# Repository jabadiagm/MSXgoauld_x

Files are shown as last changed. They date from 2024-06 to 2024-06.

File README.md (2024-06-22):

# MSXgoauld_x
MSX Goa'uld board with Xilinx XC7A35T

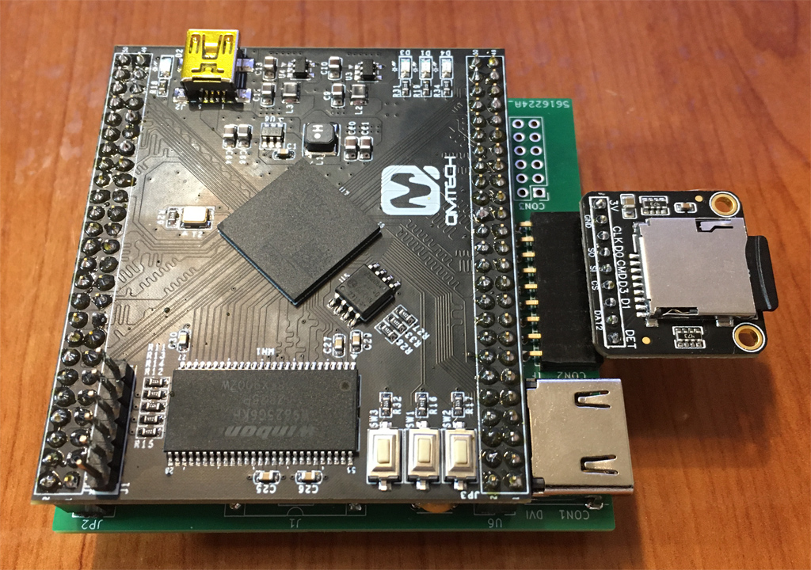
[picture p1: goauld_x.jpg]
goauld_x


MSX2+ engine in Z80 socket. It turns one MSX into an MSX2+ by replacing Z80 processor. FPGA in board contains: 
* Z80
* V9958 with hdmi output
* MSX2+ BIOS
* 4MB mapper
* RTC
* PSG through hdmi
* SCC (audio only) through hdmi
* OPLL through hdmi
* SD card interface with Nextor

## How it works:
Logic acts on bus control signals so that internal devices inside fpga take priority over external devices. 

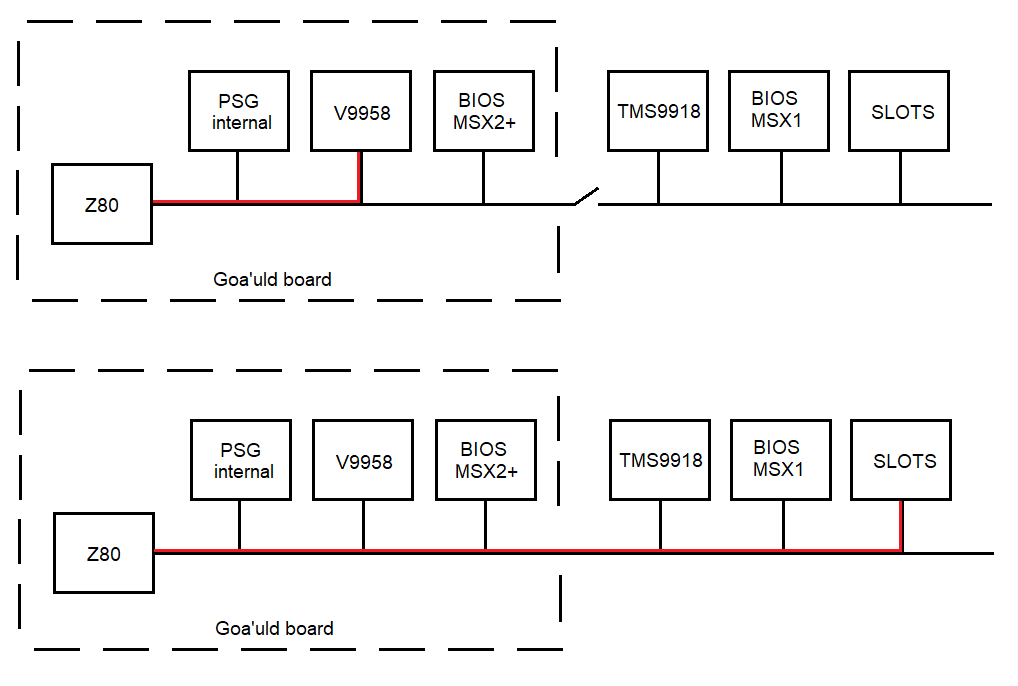
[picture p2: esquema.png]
Esquema


## Slot map

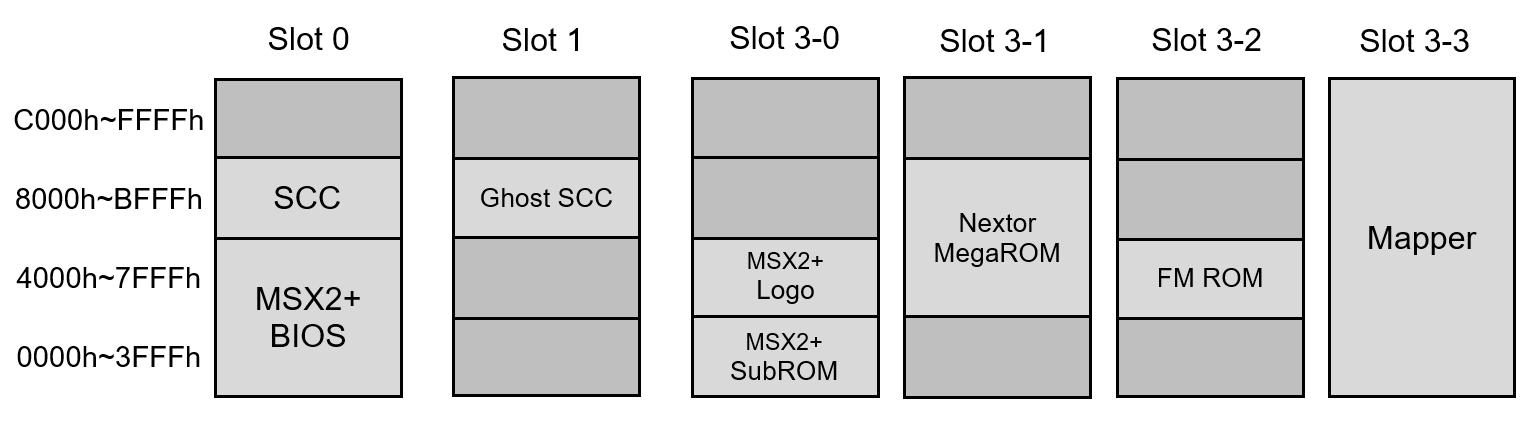
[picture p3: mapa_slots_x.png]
Slot map


Place SCC cartridges in slot 1 to get SCC sound through HDMI

## Revision 1 Board
PCB version 1 uses through hole components for ease of assembly

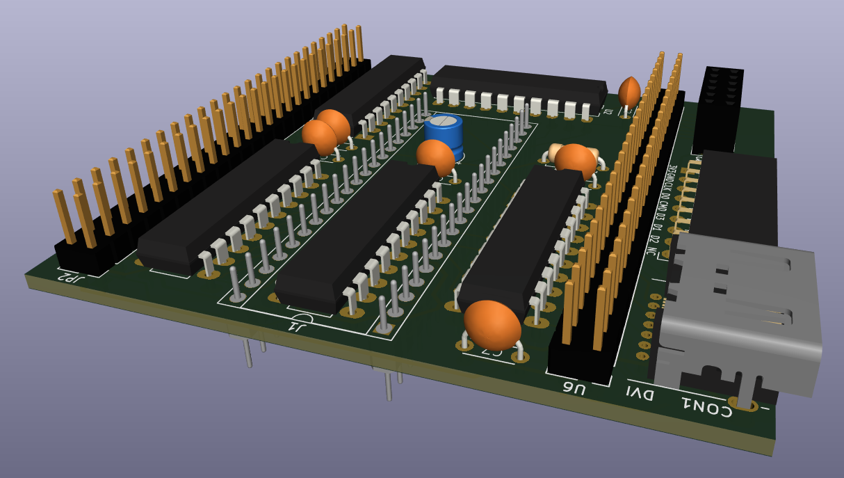
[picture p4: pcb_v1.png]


## Revision 2 Board

Revision 2 uses SOIC-20, TSSOP-20 for 74LS245 and 74LVC245 ICs, which are smaller:

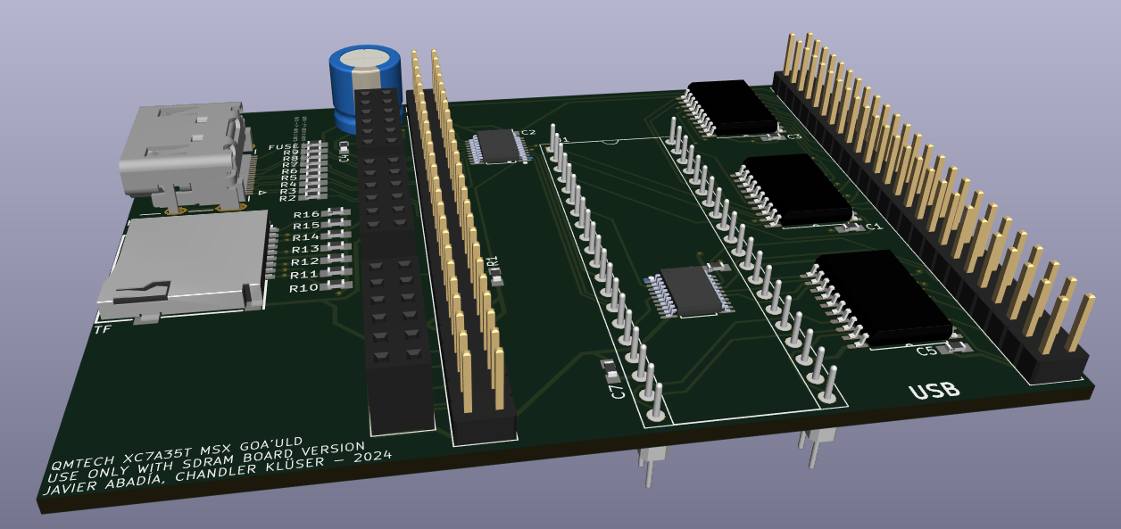
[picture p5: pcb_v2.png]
Revision 2


## Bill of materials
Main elements:
* [QMTECH Xilinx FPGA Artix7 Artix-7 XC7A35T SDRAM Core Board](https://a.aliexpress.com/_EIR63QR)
* [(PCB V1) SD SPI or SDIO Card Breakout Board - 3V](https://a.aliexpress.com/_EJ8GIw7)
* [(PCB V1) HDMI female socket/plug 19P female mount 3-row pins](https://a.aliexpress.com/_Eub6hh9)
* [40Pin Connector Header Round Needle Gold Plated 1x40 Golden Pin Single Row Male 2.54mm Breakable Pin Connector Strip](https://a.aliexpress.com/_ExPDv4F)
* [dip 2*40/ PIN double row PIN HEADER 2.54MM PITCH MALE Strip Connector 2X](https://a.aliexpress.com/_EJbEXl9)
* [2.54mm Double Row Straight Female Pin Header Socket Connector 2x25Pin](https://a.aliexpress.com/_EvLvXL1)
* 2xSN74LVC245AN
* 3x74LS245
* Platform Cable USB II / DLC10 (programmer)

## Tips/Warnings
* HDMI circuitry is unprotected in V1 board, use at your own risk
* Turn on monitor after turning on MSX, otherwise fpga may not start
* When possible, use a linear power supply to keep electrical noises low
* Get integrated circuits from trusted sources
* Use turned pins in header to avoid damages in Z80 socket
* Board is sensitive to dirty electrical contacts, way more than Z80. Keep cartridge & Z80 socket contacts clean

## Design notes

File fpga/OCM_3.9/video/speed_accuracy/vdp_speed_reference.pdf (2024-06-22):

“MOST COMMON REFERENCE FOR THE VDP SPEED ACCURACY”

PANASONIC FS-A1GT MSX turbo R / R800 (Z80 MODE) / VDP V9958

The tables for the copies:

LMMM accuracy: 16 | HMMM accuracy: 32 | YMMM accuracy: 32
TESTCOPY FS-A1GT X=32 | TESTCOPY FS-A1GT X=64 | TESTCOPY FS-A1GT X=64
Spr / Lin - Speed 50/60Hz | Spr / Lin - Speed 50/60Hz | Spr / Lin - Speed 50/60Hz
on / 212 - 1232 / 976 | on / 212 - 3520 / 2784 | on / 212 - 4192 / 3168
on / 192 - 1264 / 1008 | on / 192 - 3616 / 2880 | on / 192 - 4384 / 3360
off / 212 - 1584 / 1312 | off / 212 - 4352 / 3616 | off / 212 - 5856 / 4832
off / 192 - 1584 / 1312 | off / 192 - 4384 / 3648 | off / 192 - 5856 / 4864
--Blank-- - 1600 / 1328 | --Blank-- - 4512 / 3744 | --Blank-- - 6112 / 5120

The tables for the fills:

LMMV accuracy: 16 | HMMV accuracy: 64
TESTCOPY FS-A1GT X=32 | TESTCOPY FS-A1GT X=128
Spr / Lin - Speed 50/60Hz | Spr / Lin - Speed 50/60Hz
on / 212 - 1696 / 1344 | on / 212 - 7040 / 5632
on / 192 - 1728 / 1392 | on / 192 - 7168 / 5760
off / 212 - 1840 / 1488 | off / 212 - 7232 / 5888
off / 192 - 1856 / 1504 | off / 192 - 7360 / 5952
--Blank-- - 2128 / 1776 | --Blank-- - 8448 / 7040

The table for the lines:

LINE accuracy: 32
TESTCOPY FS-A1GT X=8 Y=8

Spr / Lin - Speed 50/60Hz

on / 212 - | 3936 | / | 3264
on / 192 - | 3968 | / | 3296
off / 212 - | 4096 | / | 3392
off / 192 - | 4096 | / | 3392
--Blank-- - | 4224 | / | 3520
( on / 212 )

Notes:

- Speed is indicated in bytes per interrupt.
- On “TestCopy” program LINES = SPEED / ACCURACY.
- The CPU frequency for the test is 3.58MHz.

The above values have been verified by KdL, 2018.05.14 These information refers to: http://map.grauw.nl/articles/vdp_commands_speed.php

More information to get the most accurate LINE speed (not yet implemented in OCM): http://map.grauw.nl/articles/vdp-vram-timing/vdp-timing.htmlhttp://map.grauw.nl/articles/vdp-vram-timing/vdp-timing-2.html

“MOST COMMON REFERENCE FOR THE VDP SPEED ACCURACY”

PHILIPS NMS-8245 MSX2 / Z80 / VDP V9938

The tables for the copies:

LMMM accuracy: 16 | HMMM accuracy: 32 | YMMM accuracy: 32
TESTCOPY NMS-8245 X=32 | TESTCOPY NMS-8245 X=64 | TESTCOPY NMS-8245 X=64
Spr / Lin - Speed 50/60Hz | Spr / Lin - Speed 50/60Hz | Spr / Lin - Speed 50/60Hz
on / 212 - 1232 / 976 | on / 212 - 3520 / 2784 | on / 212 - 4192 / 3168
on / 192 - 1264 / 1008 | on / 192 - 3616 / 2880 | on / 192 - 4384 / 3360
off / 212 - 1584 / 1312 | off / 212 - 4352 / 3616 | off / 212 - 5856 / 4832
off / 192 - 1584 / 1312 | off / 192 - 4384 / 3648 | off / 192 - 5856 / 4864
--Blank-- - 1600 / 1328 | --Blank-- - 4512 / 3744 | --Blank-- - 6112 / 5120

The tables for the fills:

LMMV accuracy: 16 | HMMV accuracy: 64
TESTCOPY NMS-8245 X=32 | TESTCOPY NMS-8245 X=128
Spr / Lin - Speed 50/60Hz | Spr / Lin - Speed 50/60Hz
on / 212 - 1696 / 1344 | on / 212 - 7040 / 5632
on / 192 - 1728 / 1392 | on / 192 - 7168 / 5760
off / 212 - 1840 / 1488 | off / 212 - 7232 / 5888
off / 192 - 1856 / 1504 | off / 192 - 7360 / 5952
--Blank-- - 2128 / 1776 | --Blank-- - 8448 / 7040

The table for the lines:

LINE accuracy: 32
TESTCOPY NMS-8245 X=8 Y=8

Spr / Lin - Speed 50/60Hz

on / 212 - | 4096 | / | 3392
on / 192 - | 4128 | / | 3424
off / 212 - | 4224 | / | 3520
off / 192 - | 4256 | / | 3520
--Blank-- - | 4352 | / | 3648
( on / 212 )

Notes:

- Speed is indicated in bytes per interrupt.
- On “TestCopy” program LINES = SPEED / ACCURACY.
- The CPU frequency for the test is 3.58MHz.

The above values have been verified by KdL, 2018.05.14 These information refers to: http://map.grauw.nl/articles/vdp_commands_speed.php

More information to get the most accurate LINE speed (not yet implemented in OCM): http://map.grauw.nl/articles/vdp-vram-timing/vdp-timing.htmlhttp://map.grauw.nl/articles/vdp-vram-timing/vdp-timing-2.html

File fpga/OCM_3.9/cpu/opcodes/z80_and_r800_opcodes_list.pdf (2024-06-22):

## Z80 And R800 Opcodes List

### Opcodes on single-byte

| 00 | 01 | 02 | 03 | 04 | 05 | 06 | 07 | 08 | 09 | 0A | 0B | 0C | 0D | 0E | 0F
00 | NOP | LD BC,ad | LD (BC),A | INC BC | INC B | DEC B | LD B,v | RLCA | EX AF,AF' | ADD HL,BC | LD A,(BC) | DEC BC | INC C | DEC C | LD C,v | RRCA
10 | DJNZ v | LD DE,ad | LD (DE),A | INC DE | INC D | DEC D | LD D,v | RLA | JR v | ADD HL,DE | LD A,(DE) | DEC DE | INC E | DEC E | LD E,v | RRA
20 | JR nz,v | LD HL,ad | LD (ad),HL | INC HL | INC H | DEC H | LD H,v | DAA | JR z,v | ADD HL,HL | LD HL,(ad) | DEC HL | INC L | DEC L | LD L,v | CPL
30 | JR nc,v | LD SP,ad | LD (ad),A | INC SP | INC (HL) | DEC (HL) | LD (HL),v | SCF | JR C,v | ADD HL,SP | LD A,(ad) | DEC SP | INC A | DEC A | LD A,v | CCF
40 | LD B,B | LD B,C | LD B,D | LD B,E | LD B,H | LD B,L | LD B,(HL) | LD B,A | LD C,B | LD C,C | LD C,D | LD C,E | LD C,H | LD C,L | LD C,(HL) | LD C,A
50 | LD D,B | LD D,C | LD D,D | LD D,E | LD D,H | LD D,L | LD D,(HL) | LD D,A | LD E,B | LD E,C | LD E,D | LD E,E | LD E,H | LD E,L | LD E,(HL) | LD E,A
60 | LD H,B | LD H,C | LD H,D | LD H,E | LD H,H | LD H,L | LD H,(HL) | LD H,A | LD L,B | LD L,C | LD L,D | LD L,E | LD L,H | LD L,L | LD L,(HL) | LD L,A
70 | LD (HL),B | LD (HL),C | LD (HL),D | LD (HL),E | LD (HL),H | LD (HL),L | HALT | LD (HL),A | LD A,B | LD A,C | LD A,D | LD A,E | LD A,H | LD A,L | LD A,(HL) | LD A,A
80 | ADD A,B | ADD A,C | ADD A,D | ADD A,E | ADD A,H | ADD A,L | ADD A,(HL) | ADD A,A | ADC A,B | ADC A,C | ADC A,D | ADC A,E | ADC A,H | ADC A,L | ADC A,(HL) | ADC A,A
90 | SUB B | SUB C | SUB D | SUB E | SUB H | SUB L | SUB (HL) | SUB A | SBC A,B | SBC A,C | SBC A,D | SBC A,E | SBC A,H | SBC A,L | SBC A,(HL) | SBC A
A0 | AND B | AND C | AND D | AND E | AND H | AND L | AND (HL) | AND A | XOR B | XOR C | XOR D | XOR E | XOR H | XOR L | XOR (HL) | XOR A
B0 | OR B | OR C | OR D | OR E | OR H | OR L | OR (HL) | OR A | CP B | CP C | CP D | CP E | CP H | CP L | CP (HL) | CP A
C0 | RET nz | POP BC | JP nz,ad | JP ad | CALL nz,ad | PUSH BC | ADD A,v | RST 0h | RET z | RET | JP z,ad | * | CALL z,ad | CALL ad | ADC A,v | RST 8h
D0 | RET nc | POP DE | JP nc,ad | OUT (v),A | CALL nc,ad | PUSH DE | SUB v | RST 10h | RET c | EXX | JP c,ad | IN A,(v) | CALL c,ad | ** | SBC A,v | RST 18h
E0 | RET po | POP HL | JP po,ad | EX (SP),HL | CALL po,ad | PUSH HL | AND v | RST 20h | RET pe | JP (HL) | JP pe,ad | EX DE,HL | CALL pe,ad | *** | XOR v | RST 28h
F0 | RET p | POP AF | JP p,ad | DI | CALL p,ad | PUSH AF | OR v | RST 30h | RET m | LD SP,HL | JP m,ad | EI | CALL m,ad | **** | CP v | RST 38h

Note: Some of these opcodes are followed by one or two bytes to specify the value v or the address ad.

### (*) Opcodes extended on 2-byte which begin with CBh

CB | 00 | 01 | 02 | 03 | 04 | 05 | 06 | 07 | 08 | 09 | 0A | 0B | 0C | 0D | 0E | 0F
00 | RLC B | RLC C | RLC D | RLC E | RLC H | RLC L | RLC (HL) | RLC A | RRC B | RRC C | RRC D | RRC E | RRC H | RRC H | RRC (HL) | RRC A
10 | RL B | RL C | RL D | RL E | RL H | RL L | RL (HL) | RL A | RR B | RR C | RR D | RR E | RR H | RR H | RR (HL) | RR A
20 | SLA B | SLA C | SLA D | SLA E | SLA H | SLA L | SLA (HL) | SLA A | SRA B | SRA C | SRA D | SRA E | SRA H | SRA H | SRA (HL) | SRA A
30 | SLL B | SLL C | SLL D | SLL E | SLL H | SLL L | SLL (HL) | SLL A | SRL B | SRL C | SRL D | SRL E | SRL H | SRL H | SRL (HL) | SRL A
40 | BIT 0,B | BIT 0,C | BIT 0,D | BIT 0,E | BIT 0,H | BIT 0,L | BIT 0,(HL) | BIT 0,A | BIT 1,B | BIT 1,C | BIT 1,D | BIT 1,E | BIT 1,H | BIT 1,L | BIT 1,(HL) | BIT 1,A
50 | BIT 2,B | BIT 2,C | BIT 2,D | BIT 2,E | BIT 2,H | BIT 2,L | BIT 2,(HL) | BIT 2,A | BIT 3,B | BIT 3,C | BIT 3,D | BIT 3,E | BIT 3,H | BIT 3,L | BIT 3,(HL) | BIT 3,A
60 | BIT 4,B | BIT 4,C | BIT 4,D | BIT 4,E | BIT 4,H | BIT 4,L | BIT 4,(HL) | BIT 4,A | BIT 5,B | BIT 5,C | BIT 5,D | BIT 5,E | BIT 5,H | BIT 5,L | BIT 5,(HL) | BIT 5,A
70 | BIT 6,B | BIT 6,C | BIT 6,D | BIT 6,E | BIT 6,H | BIT 6,L | BIT 6,(HL) | BIT 6,A | BIT 7,B | BIT 7,C | BIT 7,D | BIT 7,E | BIT 7,H | BIT 7,L | BIT 7,(HL) | BIT 7,A
80 | RES 0,B | RES 0,C | RES 0,D | RES 0,E | RES 0,H | RES 0,L | RES 0,(HL) | RES 0,A | RES 1,B | RES 1,C | RES 1,D | RES 1,E | RES 1,H | RES 1,L | RES 1,(HL) | RES 1,A
90 | RES 2,B | RES 2,C | RES 2,D | RES 2,E | RES 2,H | RES 2,L | RES 2,(HL) | RES 2,A | RES 3,B | RES 3,C | RES 3,D | RES 3,E | RES 3,H | RES 3,L | RES 3,(HL) | RES 3,A
A0 | RES 4,B | RES 4,C | RES 4,D | RES 4,E | RES 4,H | RES 4,L | RES 4,(HL) | RES 4,A | RES 5,B | RES 5,C | RES 5,D | RES 5,E | RES 5,H | RES 5,L | RES 5,(HL) | RES 5,A
B0 | RES 6,B | RES 6,C | RES 6,D | RES 6,E | RES 6,H | RES 6,L | RES 6,(HL) | RES 6,A | RES 7,B | RES 7,C | RES 7,D | RES 7,E | RES 7,H | RES 7,L | RES 7,(HL) | RES 7,A
C0 | SET 0,B | SET 0,C | SET 0,D | SET 0,E | SET 0,H | SET 0,L | SET 0,(HL) | SET 0,A | SET 1,B | SET 1,C | SET 1,D | SET 1,E | SET 1,H | SET 1,L | SET 1,(HL) | SET 1,A
D0 | SET 2,B | SET 2,C | SET 2,D | SET 2,E | SET 2,H | SET 2,L | SET 2,(HL) | SET 2,A | SET 3,B | SET 3,C | SET 3,D | SET 3,E | SET 3,H | SET 3,L | SET 3,(HL) | SET 3,A
E0 | SET 4,B | SET 4,C | SET 4,D | SET 4,E | SET 4,H | SET 4,L | SET 4,(HL) | SET 4,A | SET 5,B | SET 5,C | SET 5,D | SET 5,E | SET 5,H | SET 5,L | SET 5,(HL) | SET 5,A
F0 | SET 6,B | SET 6,C | SET 6,D | SET 6,E | SET 6,H | SET 6,L | SET 6,(HL) | SET 6,A | SET 7,B | SET 7,C | SET 7,D | SET 7,E | SET 7,H | SET 7,L | SET 7,(HL) | SET 7,A

### (**) Opcodes extended on two-byte which begin with DDh (for register IX)

DD | 00 | 01 | 02 | 03 | 04 | 05 | 06 | 07 | 08 | 09 | 0A | 0B | 0C | 0D | 0E | 0F
00 | | | | | | | | | | ADD IX,BC
10 | | | | | | | | | | ADD IX,DE
20 | | LD IX,ad | LD (ad),IX | INC IX | INC IXH | DEC IXH | LD IXH,v | | | ADD IX,IX | LD IX,(ad) | DEC IX | INC IXL | DEC IXL | LD IXL,v
30 | | | | | INC (IX+v) | DEC (IX+v) | LD (IX+v),v | | | ADD IX,SP
40 | | | | | LD B,IXH | LD B,IXL | LD B,(IX+v) | | | | | | LD C,IXH | LD C,IXL | LD C,(IX+v)
50 | | | | | LD D,IXH | LD D,IXL | LD D,(IX+v) | | | | | | LD E,IXH | LD E,IXL | LD E,(IX+v)
60 | LD IXH,B | LD IXH,C | LD IXH,D | LD IXH,E | LD IXH,IXH | LD IXH,IXL | LD H,(IX+v) | LD IXH,A | LD IXL,B | LD IXL,C | LD IXL,D | LD IXL,E | LD IXL,IXH | LD IXL,IXL | LD L,(IX+v) | LD IXL,A
70 | LD (IX+v),B | LD (IX+v),C | LD (IX+v),D | LD (IX+v),E | LD (IX+v),H | LD (IX+v),L | | LD (IX+v),A | | | | | LD A,IXH | LD A,IXL | LD A,(IX+v)
80 | | | | | ADD A,IXH | ADD A,IXL | ADD A,(IX+v) | | | | | | ADC A,IXH | ADC A,IXL | ADC A,(IX+v)
90 | | | | | SUB IXH | SUB IXL | SUB (IX+v) | | | | | | SBC A,IXH | SBC A,IXL | SBC A,(IX+v)
A0 | | | | | AND IXH | AND IXL | AND (IX+v) | | | | | | XOR IXH | XOR IXL | XOR (IX+v)
B0 | | | | | OR IXH | OR IXL | OR (IX+v) | | | | | | CP IXH | CP IXL | CP (IX+v)
C0 | | | | | | | | | | | | **²

D0
E0 | | POP IX | | EX (SP),IX | | PUSH IX | | | | JP (IX)
F0 | | | | | | | | | | LD SP,IX

Note: Some of these opcodes are followed by one or two bytes to specify the value v or the address ad.

### (**²) Opcodes extended on four-byte which begin with DDh+CBh+v (for register IX)

DD+CB+v | 00 | 01 | 02 | 03 | 04 | 05 | 06 | 07 | 08 | 09 | 0A | 0B | 0C | 0D | 0E | 0F
00 | RLC (v+IX) LD B,(v+IX) | RLC (IX+v) LD C,(IX+v) | RLC (v+IX) LD D,(v+IX) | RLC (v+IX) LD E,(v+IX) | RLC (v+IX) LD H,(v+IX) | RLC (v+IX) LD L,(v+IX) | RLC (v+IX) | RLC (v+IX) LD A,(v+IX) | RRC (v+IX) LD B,(v+IX) | RRC (v+IX) LD C,(v+IX) | RRC (v+IX) LD D,(v+IX) | RRC (v+IX) LD E,(v+IX) | RRC (v+IX) LD H,(v+IX) | RRC (v+IX) LD L,(v+IX) | RRC (v+IX) | RRC (v+IX) LD A,(v+IX)
10 | RL (v+IX) LD B,(v+IX) | RL (IX+v) LD C,(IX+v) | RL (v+IX) LD D,(v+IX) | RL (v+IX) LD E,(v+IX) | RL (v+IX) LD H,(v+IX) | RL (v+IX) LD L,(v+IX) | RL (v+IX) | RL (v+IX) LD A,(v+IX) | RR (v+IX) LD B,(v+IX) | RR (v+IX) LD C,(v+IX) | RR (v+IX) LD D,(v+IX) | RR (v+IX) LD E,(v+IX) | RR (v+IX) LD H,(v+IX) | LD L,(v+IX) RR (v+IX) | RR (v+IX) | RR (v+IX) LD A,(v+IX)
20 | SLA (v+IX) LD B,(v+IX) | SLA (IX+v) LD C,(IX+v) | SLA (v+IX) LD D,(v+IX) | SLA (v+IX) LD E,(v+IX) | SLA (v+IX) LD H,(v+IX) | SLA (v+IX) LD L,(v+IX) | SLA (v+IX) | SLA (v+IX) LD A,(v+IX) | SRA (v+IX) LD B,(v+IX) | SRA (v+IX) LD C,(v+IX) | SRA (v+IX) LD D,(v+IX) | SRA (v+IX) LD E,(v+IX) | SRA (v+IX) LD H,(v+IX) | SRA (v+IX) LD L,(v+IX) | SRA (v+IX) | SRA (v+IX) LD A,(v+IX)
30 | SLL (v+IX) LD B,(v+IX) | SLL (IX+v) LD C,(IX+v) | SLL (v+IX) LD D,(v+IX) | SLL (v+IX) LD E,(v+IX) | SLL (v+IX) LD H,(v+IX) | SLL (v+IX) LD L,(v+IX) | SLL (v+IX) | SRL (v+IX) LD A,(v+IX) | SRL (v+IX) LD B,(v+IX) | SRL (v+IX) LD C,(v+IX) | SRL (v+IX) LD D,(v+IX) | SRL (v+IX) LD E,(v+IX) | SRL (v+IX) LD H,(v+IX) | SRL (v+IX) LD L,(v+IX) | SRL (v+IX) | SRL (v+IX) LD A,(v+IX)
40 | BIT 0,(v+IX) LD B,(v+IX) | BIT 0,(IX+v) LD C,(IX+v) | BIT 0,(v+IX) LD D,(v+IX) | BIT 0,(v+IX) LD E,(v+IX) | BIT 0,(v+IX) LD H,(v+IX) | BIT 0,(v+IX) LD L,(v+IX) | BIT 0, (v+IX) | BIT 0,(v+IX) LD A,(v+IX) | BIT 1,(v+IX) LD B,(v+IX) | BIT 1,(v+IX) LD C,(v+IX) | BIT 1,(v+IX) LD D,(v+IX) | BIT 1,(v+IX) LD E,(v+IX) | BIT 1,(v+IX) LD H,(v+IX) | BIT 1,(v+IX) LD L,(v+IX) | BIT 1, (v+IX) | BIT 1,(v+IX) LD A,(v+IX)
50 | BIT 2,(v+IX) LD B,(v+IX) | BIT 2,(IX+v) LD C,(IX+v) | BIT 2,(v+IX) LD D,(v+IX) | BIT 2,(v+IX) LD E,(v+IX) | BIT 2,(v+IX) LD H,(v+IX) | BIT 2,(v+IX) LD L,(v+IX) | BIT 2, (v+IX) | BIT 2,(v+IX) LD A,(v+IX) | BIT 3,(v+IX) LD B,(v+IX) | BIT 3,(v+IX) LD C,(v+IX) | BIT 3,(v+IX) LD D,(v+IX) | BIT 3,(v+IX) LD E,(v+IX) | BIT 3,(v+IX) LD H,(v+IX) | BIT 3,(v+IX) LD L,(v+IX) | BIT 3, (v+IX) | BIT 3,(v+IX) LD A,(v+IX)
60 | BIT 4,(v+IX) LD B,(v+IX) | BIT 4,(IX+v) LD C,(IX+v) | BIT 4,(v+IX) LD D,(v+IX) | BIT 4,(v+IX) LD E,(v+IX) | BIT 4,(v+IX) LD H,(v+IX) | BIT 4,(v+IX) LD L,(v+IX) | BIT 4, (v+IX) | BIT 4,(v+IX) LD A,(v+IX) | BIT 5,(v+IX) LD B,(v+IX) | BIT 5,(v+IX) LD C,(v+IX) | BIT 5,(v+IX) LD D,(v+IX) | BIT 5,(v+IX) LD E,(v+IX) | BIT 5,(v+IX) LD H,(v+IX) | BIT 5,(v+IX) LD L,(v+IX) | BIT 5, (v+IX) | BIT 5,(v+IX) LD A,(v+IX)
70 | BIT 6,(v+IX) LD B,(v+IX) | BIT 6,(IX+v) LD C,(IX+v) | BIT 6,(v+IX) LD D,(v+IX) | BIT 6,(v+IX) LD E,(v+IX) | BIT 6,(v+IX) LD H,(v+IX) | BIT 6,(v+IX) LD L,(v+IX) | BIT 6, (v+IX) | BIT 6,(v+IX) LD A,(v+IX) | BIT 7,(v+IX) LD B,(v+IX) | BIT 7,(v+IX) LD C,(v+IX) | BIT 7,(v+IX) LD D,(v+IX) | BIT 7,(v+IX) LD E,(v+IX) | BIT 7,(v+IX) LD H,(v+IX) | BIT 7,(v+IX) LD L,(v+IX) | BIT 7, (v+IX) | BIT 7,(v+IX) LD A,(v+IX)
80 | RES 0,(v+IX) LD B,(v+IX) | RES 0,(IX+v) LD C,(IX+v) | RES 0,(v+IX) LD D,(v+IX) | RES 0,(v+IX) LD E,(v+IX) | RES 0,(v+IX) LD H,(v+IX) | RES 0,(v+IX) LD L,(v+IX) | RES 0, (v+IX) | RES 0,(v+IX) LD A,(v+IX) | RES 1,(v+IX) LD B,(v+IX) | RES 1,(v+IX) LD C,(v+IX) | RES 1,(v+IX) LD D,(v+IX) | RES 1,(v+IX) LD E,(v+IX) | RES 1,(v+IX) LD H,(v+IX) | RES 1,(v+IX) LD L,(v+IX) | RES 1, (v+IX) | RES 1,(v+IX) LD A,(v+IX)
90 | RES 2,(v+IX) LD B,(v+IX) | RES 2,(IX+v) LD C,(IX+v) | RES 2,(v+IX) LD D,(v+IX) | RES 2,(v+IX) LD E,(v+IX) | RES 2,(v+IX) LD H,(v+IX) | BIT 2,(v+IX) LD L,(v+IX) | RES 2, (v+IX) | RES 2,(v+IX) LD A,(v+IX) | RES 3,(v+IX) LD B,(v+IX) | RES 3,(v+IX) LD C,(v+IX) | RES 3,(v+IX) LD D,(v+IX) | RES 3,(v+IX) LD E,(v+IX) | RES 3,(v+IX) LD H,(v+IX) | RES 3,(v+IX) LD L,(v+IX) | RES 3, (v+IX) | RES 3,(v+IX) LD A,(v+IX)
A0 | RES 4,(v+IX) LD B,(v+IX) | RES 4,(IX+v) LD C,(IX+v) | RES 4,(v+IX) LD D,(v+IX) | RES 4,(v+IX) LD E,(v+IX) | RES 4,(v+IX) LD H,(v+IX) | RES 4,(v+IX) LD L,(v+IX) | RES 4, (v+IX) | RES 4,(v+IX) LD A,(v+IX) | RES 5,(v+IX) LD B,(v+IX) | RES 5,(v+IX) LD C,(v+IX) | RES 5,(v+IX) LD D,(v+IX) | RES 5,(v+IX) LD E,(v+IX) | RES 5,(v+IX) LD H,(v+IX) | RES 5,(v+IX) LD L,(v+IX) | RES 5, (v+IX) | RES 5,(v+IX) LD A,(v+IX)
B0 | RES 6,(v+IX) LD B,(v+IX) | RES 6,(IX+v) LD C,(IX+v) | RES 6,(v+IX) LD D,(v+IX) | RES 6,(v+IX) LD E,(v+IX) | RES 6,(v+IX) LD H,(v+IX) | RES 6,(v+IX) LD L,(v+IX) | RES 6, (v+IX) | RES 6,(v+IX) LD A,(v+IX) | RES 7,(v+IX) LD B,(v+IX) | RES 7,(v+IX) LD C,(v+IX) | RES 7,(v+IX) LD D,(v+IX) | RES 7,(v+IX) LD E,(v+IX) | RES 7,(v+IX) LD H,(v+IX) | RES 7,(v+IX) LD L,(v+IX) | RES 7, (v+IX) | RES 7,(v+IX) LD A,(v+IX)
C0 | SET 0,(v+IX) LD B,(v+IX) | SET 0,(IX+v) LD C,(IX+v) | SET 0,(v+IX) LD D,(v+IX) | SET 0,(v+IX) LD E,(v+IX) | SET 0,(v+IX) LD H,(v+IX) | SET 0,(v+IX) LD L,(v+IX) | SET 0, (v+IX) | SET 0,(v+IX) LD A,(v+IX) | SET 1,(v+IX) LD B,(v+IX) | SET 1,(v+IX) LD C,(v+IX) | SET 1,(v+IX) LD D,(v+IX) | SET 1,(v+IX) LD E,(v+IX) | SET 1,(v+IX) LD H,(v+IX) | SET 1,(v+IX) LD L,(v+IX) | SET 1, (v+IX) | SET 1,(v+IX) LD A,(v+IX)
D0 | SET 2,(v+IX) LD B,(v+IX) | SET 2,(IX+v) LD C,(IX+v) | SET 2,(v+IX) LD D,(v+IX) | SET 2,(v+IX) LD E,(v+IX) | SET 2,(v+IX) LD H,(v+IX) | SET 2,(v+IX) LD L,(v+IX) | SET 2, (v+IX) | SET 2,(v+IX) LD A,(v+IX) | SET 3,(v+IX) LD B,(v+IX) | SET 3,(v+IX) LD C,(v+IX) | SET 3,(v+IX) LD D,(v+IX) | SET 3,(v+IX) LD E,(v+IX) | SET 3,(v+IX) LD H,(v+IX) | SET 3,(v+IX) LD L,(v+IX) | SET 3, (v+IX) | SET 3,(v+IX) LD A,(v+IX)
E0 | SET 4,(v+IX) LD B,(v+IX) | SET 4,(IX+v) LD C,(IX+v) | SET 4,(v+IX) LD D,(v+IX) | SET 4,(v+IX) LD E,(v+IX) | SET 4,(v+IX) LD H,(v+IX) | SET 4,(v+IX) LD L,(v+IX) | SET 4, (v+IX) | SET 4,(v+IX) LD A,(v+IX) | SET 5,(v+IX) LD B,(v+IX) | SET 5,(v+IX) LD C,(v+IX) | SET 5,(v+IX) LD D,(v+IX) | SET 5,(v+IX) LD E,(v+IX) | SET 5,(v+IX) LD H,(v+IX) | SET 5,(v+IX) LD L,(v+IX) | SET 5, (v+IX) | SET 5,(v+IX) LD A,(v+IX)
F0 | SET 6,(v+IX) LD B,(v+IX) | SET 6,(IX+v) LD C,(IX+v) | SET 6,(v+IX) LD D,(v+IX) | SET 6,(v+IX) LD E,(v+IX) | SET 6,(v+IX) LD H,(v+IX) | SET 6,(v+IX) LD L,(v+IX) | SET 6, (v+IX) | SET 6,(v+IX) LD A,(v+IX) | SET 7,(v+IX) LD B,(v+IX) | SET 7,(v+IX) LD C,(v+IX) | SET 7,(v+IX) LD D,(v+IX) | SET 7,(v+IX) LD E,(v+IX) | SET 7,(v+IX) LD H,(v+IX) | SET 7,(v+IX) LD L,(v+IX) | SET 7, (v+IX) | SET 7,(v+IX) LD A,(v+IX)

Note: These opcodes have a byte between the third and fourth bytes to specify the value (v).

### (***) Opcodes extended on two-byte which begin with EDh

ED | 00 | 01 | 02 | 03 | 04 | 05 | 06 | 07 | 08 | 09 | 0A | 0B | 0C | 0D | 0E | 0F

00

10

20

30

40 | IN B,(C) | OUT (C),B | SBC HL,BC | LD (ad),BC | NEG | RETN | IM 0 | LD i,A | IN C,(C) | OUT (C),C | ADC HL,BC | LD BC,(ad) | NEG | RETI | IM 0 | LD R,A
50 | IN D,(C) | OUT (C),D | SBC DE,BC | LD (ad),DE | NEG | RETN | IM 1 | LD A,i | IN E,(C) | OUT (C),E | ADC HL,DE | LD DE,(ad) | NEG | RETI | IM 2 | LD A,R
60 | IN H,(C) | OUT (C),H | SBC HL,HL | LD (ad),HL | NEG | RETN | IM 0 | RRD | IN L,(C) | OUT (C),L | ADC HL,HL | LD HL,(ad) | NEG | RETI | IM 0 | RLD
70 | IN (C) | OUT (C),0 | SBC HL,SP | LD (ad),SP | NEG | RETN | IM 1 | NOP | IN A,(C) | OUT (C),A | ADC HL,SP | LD SP,(ad) | NEG | RETI | IM 2 | LD R,R

80

90

A0 | LDI | CPI | INI | OUTI | | | | | LDD | CPD | IND | OUTD
B0 | LDIR | CPIR | INIR | OTIR | | | | | LDDR | CPDR | INDR | OUTR
C0 | | MULUB A,B | | MULUW HL,BC | | | | | | MULUB A,C
D0 | | MULUB A,D | | MULUW HL,DE | | | | | | MULUB A,E
E0 | | MULUB A,H | | MULUW HL,HL | | | | | | MULUB A,L
F0 | | MULUB A,(HL) | | MULUW HL,SP | | | | | | MULUB A,A

Note: Some of these opcodes are followed by two bytes to specify an address (ad).

### (****) Opcodes extended on two or three byte which begin with FDh (register IY)

See the tables of extended opcodes which begin with DDh and DDh+CBh. Replace DDh by FDh to obtain the code of statements for register IY.

### Description of colors

- The green statements refer to inputs/outputs.
- The purple statements concern interruptions.
- The statements in red are undocumented by Zilog for the Z80. Some Z80-compatible CPUs do not have all of these statements.
- The statements in sky blue are unsigned multiplications. These are specific statements for the R800 (MSX turbo R). MULUB multiplies the two indicated 8-bit registers and sets the result in HL. MULUW multiplies both 16-bit registers and sets the result in HL (MSB) and DE (LSB). Barred statements are not guarantees of operation.

### About Undocumented Statements (in red)

- Undocumented statements are rarely used in MSX programs.
- The statement SLL of opcodes CBh 30h ~ CBh 37h (in dark red) has been replaced on R800 by SLA (same as CBh 20h ~ CBh 27h).
- On Z80 the undocumented opcodes which begin with DDh CBh or FDh CBh correspond to the execution of the two statements indicated in the cell at same time.
- Empty cells correspond to a NOP whose execution takes 8T states and increment by two the register R. Same for the mirrors of NEG, RETN and IM (in italic and darker red). Same also for opcodes which begin with DDh CBh and FDH CBh.
- All statements for the registers IXH, IXL, IYH and IYL are official statements on R800.

### (List v1.10 by GDX)

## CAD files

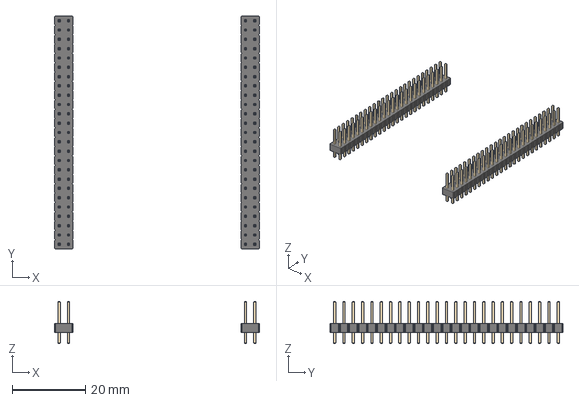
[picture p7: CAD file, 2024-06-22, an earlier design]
kicad/v1/librerias/3D/Qmtech_xc7a15t_35t.step
55.9 x 63.5 x 11.5 mm
PinHeader_2x25_P254mm_Vertical x 2

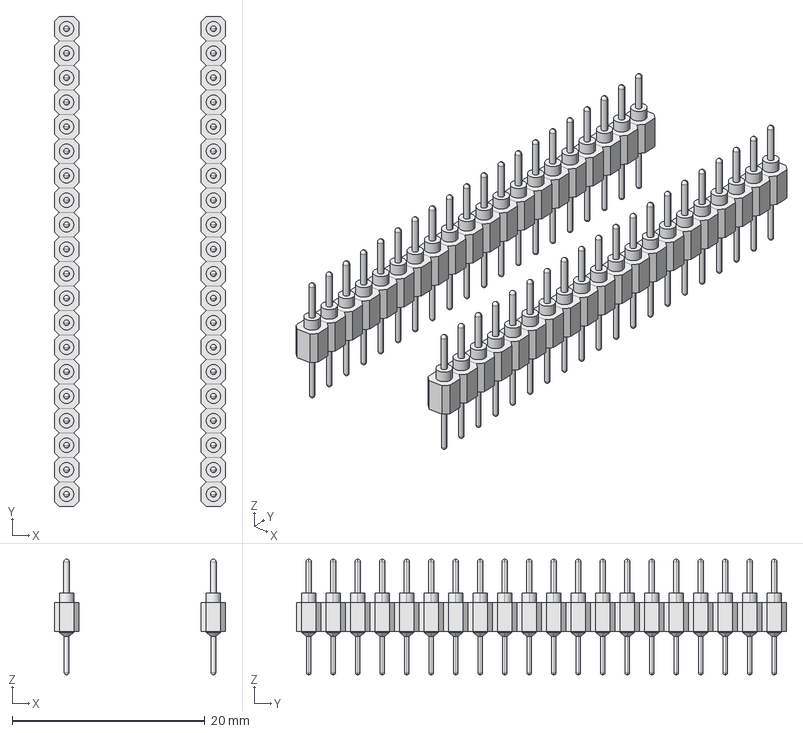
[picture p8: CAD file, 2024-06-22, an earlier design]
kicad/v1/librerias/3D/Z80_PINHEADER.step
17.8 x 50.8 x 12.0 mm
Header-Male-round x 40

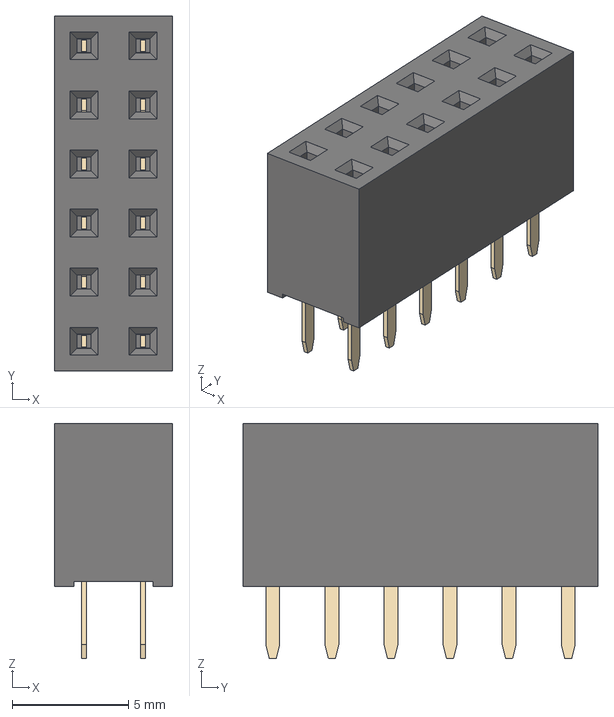
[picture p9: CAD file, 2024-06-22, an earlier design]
kicad/v1/librerias/3D/PinSocket_2x06_P2.54mm_Vertical.step
5.08 x 15.2 x 10.1 mm

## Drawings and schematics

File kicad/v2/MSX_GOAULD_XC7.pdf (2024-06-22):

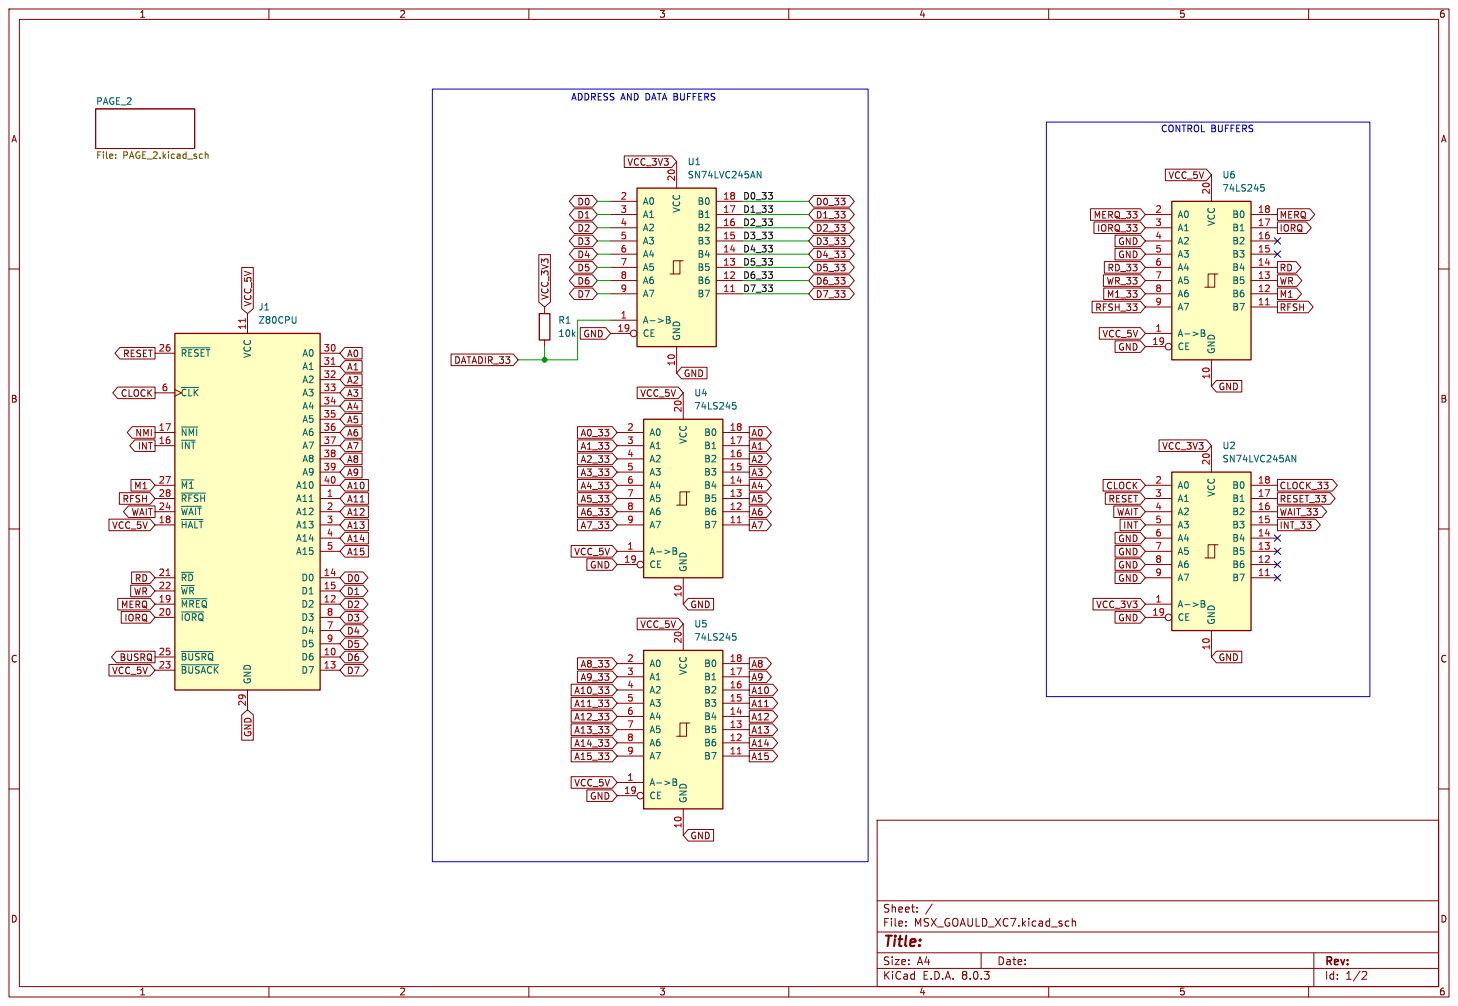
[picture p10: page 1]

Id: 1/2 Title: File: MSX_GOAULD_XC7.kicad_sch Sheet: /

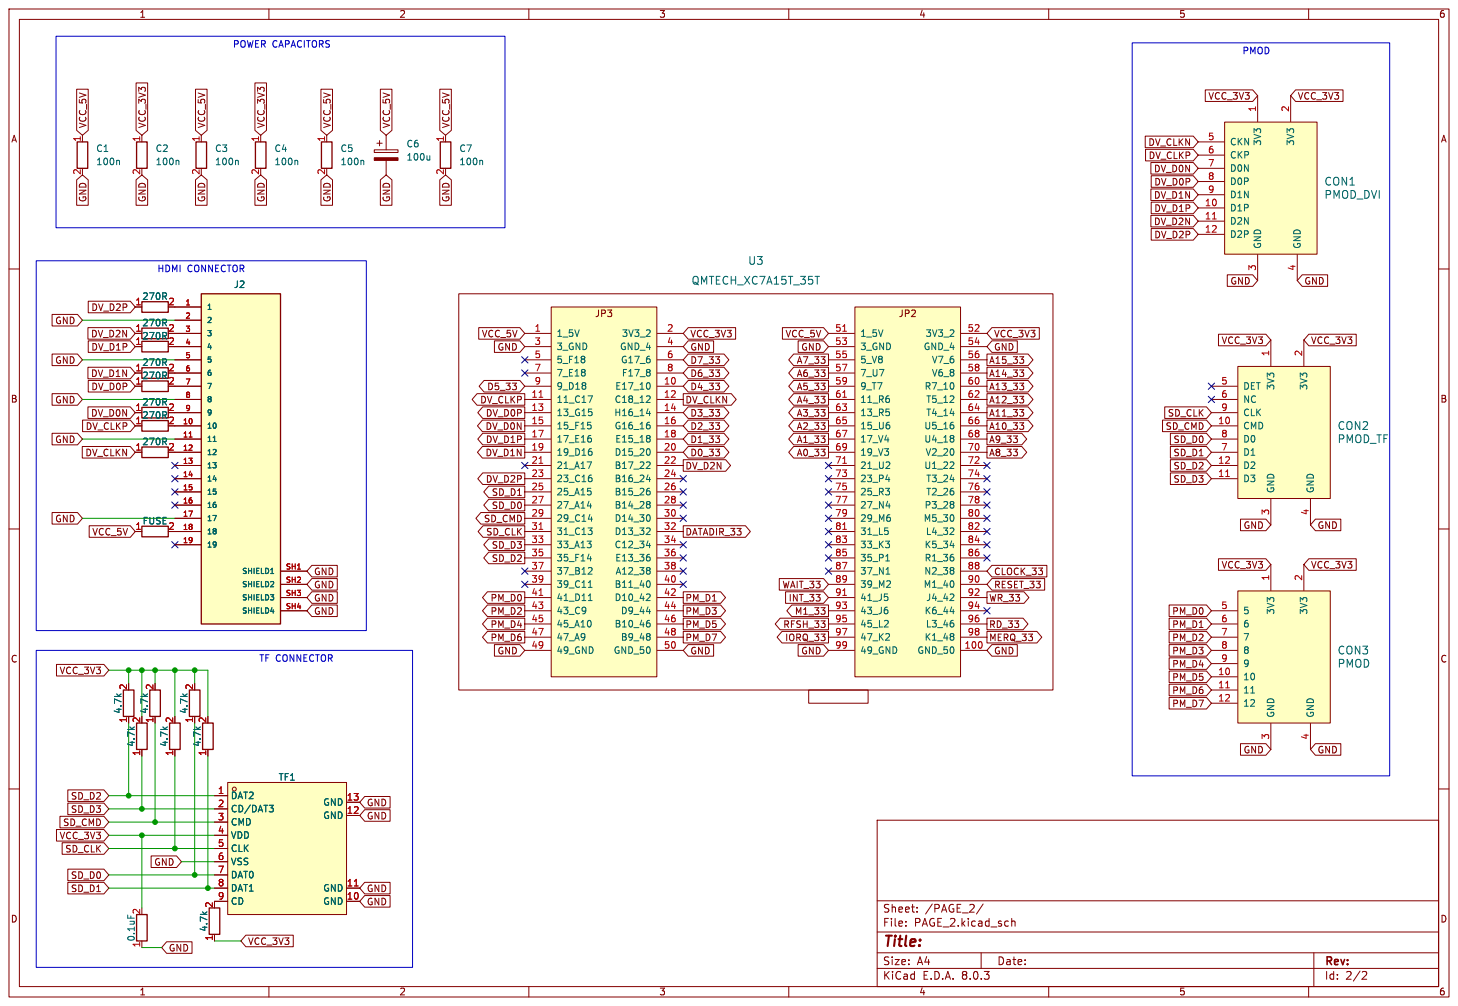
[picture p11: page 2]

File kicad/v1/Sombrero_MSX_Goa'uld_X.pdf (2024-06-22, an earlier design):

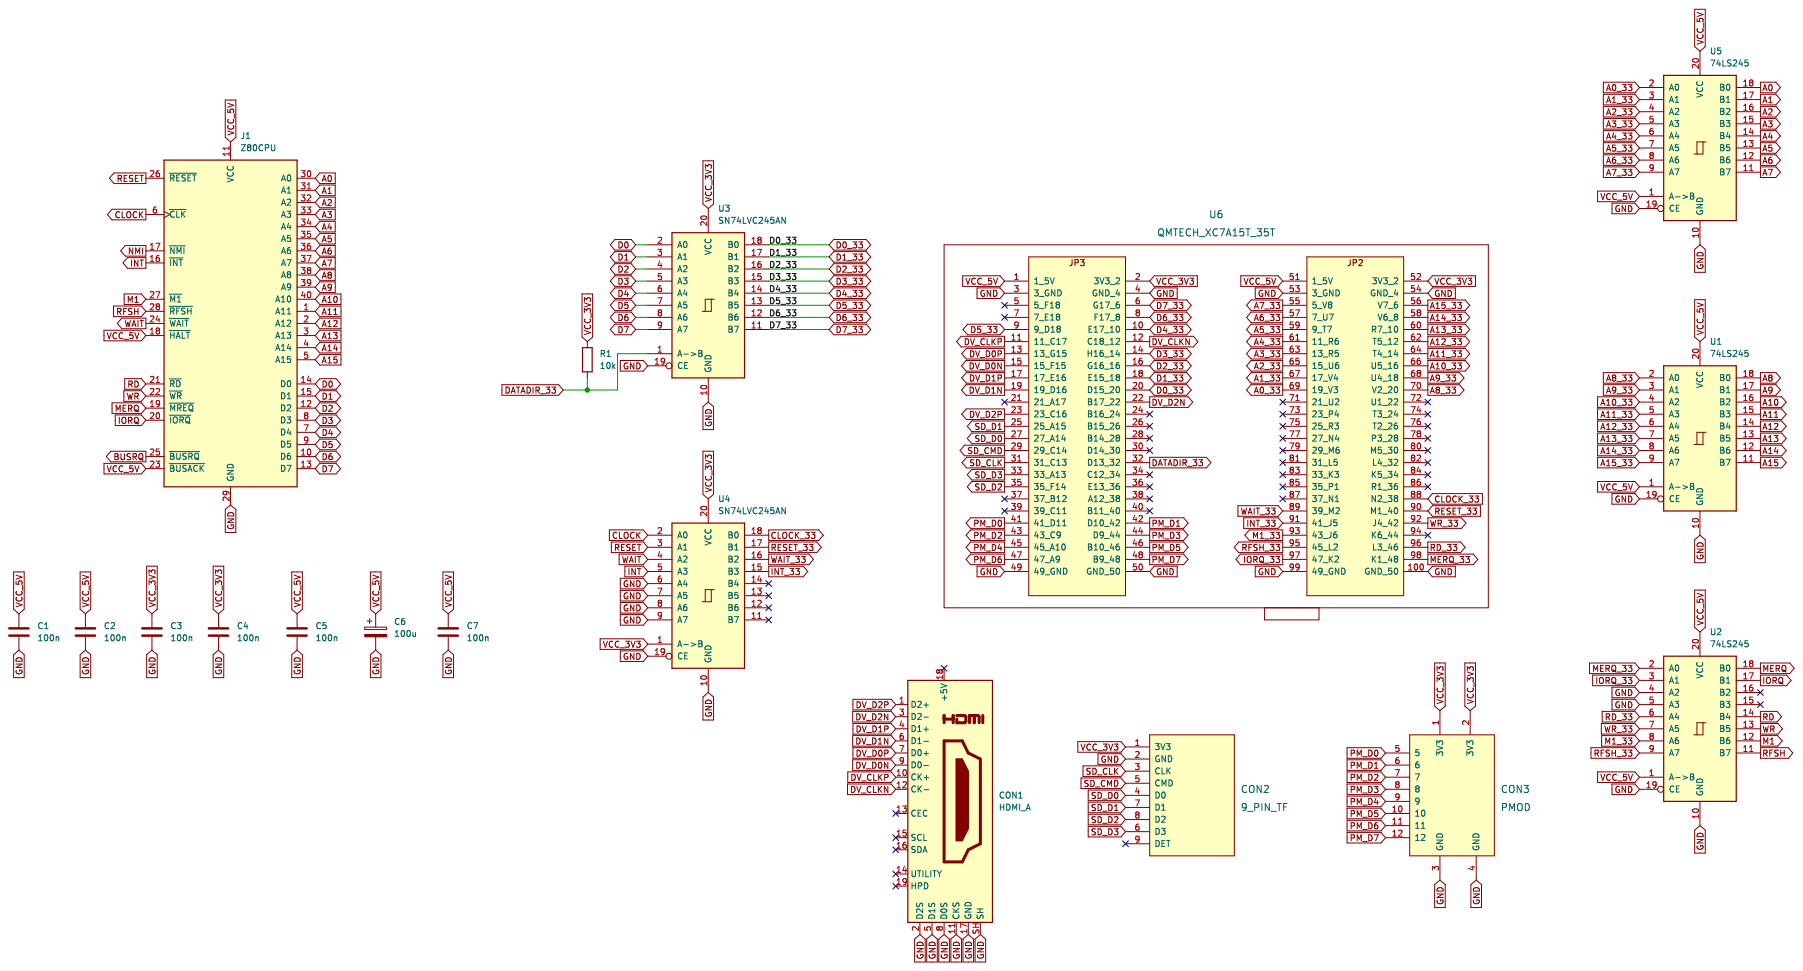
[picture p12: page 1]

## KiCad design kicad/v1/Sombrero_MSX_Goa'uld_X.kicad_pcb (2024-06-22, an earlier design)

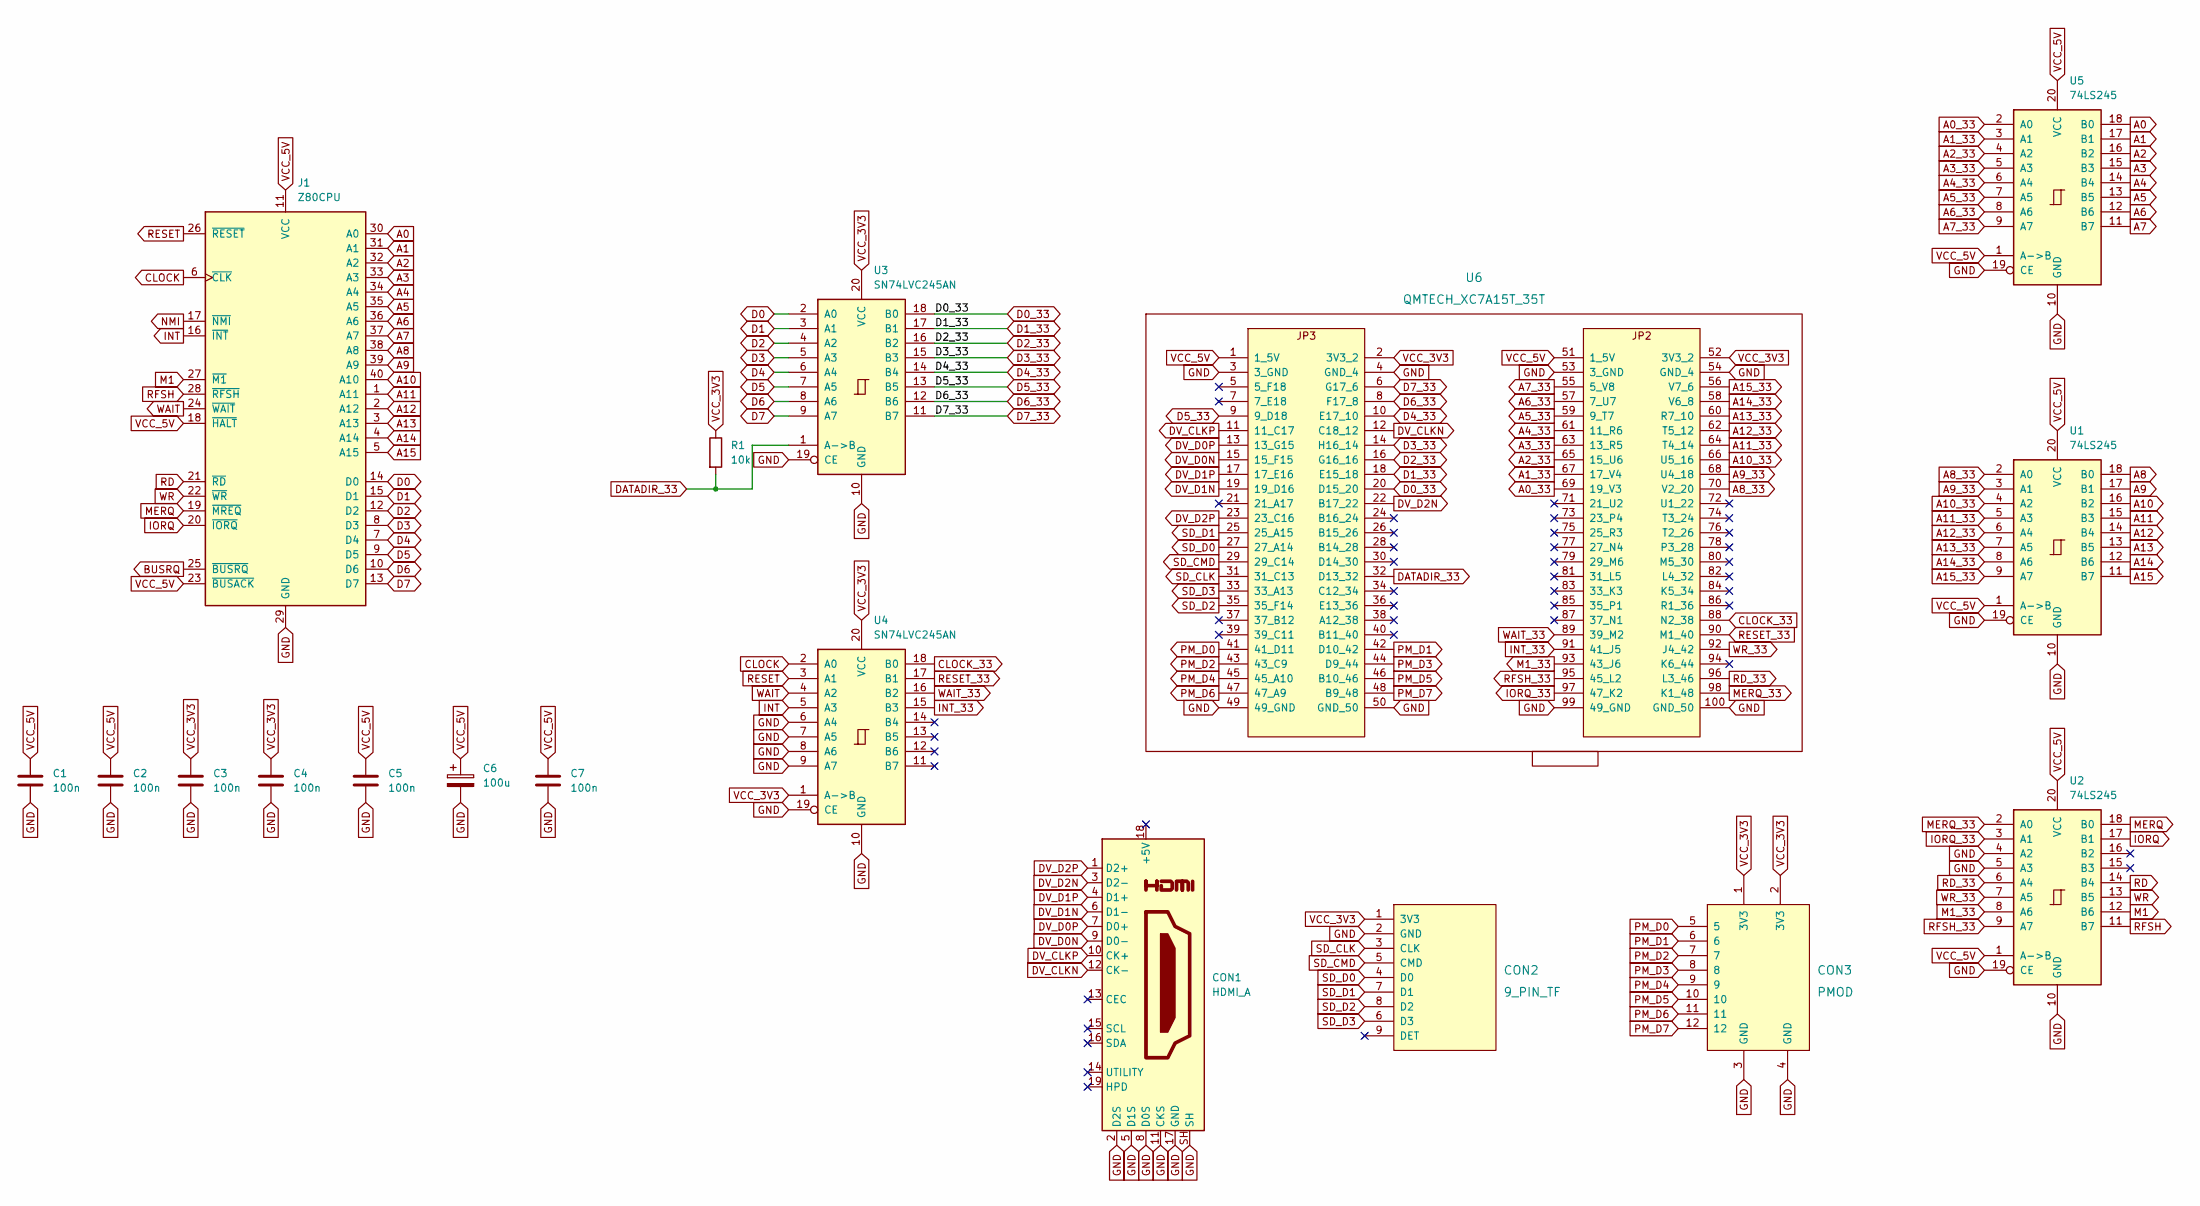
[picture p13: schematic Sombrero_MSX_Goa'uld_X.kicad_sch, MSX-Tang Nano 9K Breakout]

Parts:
C1, C2, C3, C4, C5, C7: 100n; C_Disc_D4.3mm_W1.9mm_P5.00mm
C6: 100u; CP_Radial_D5.0mm_P2.50mm
CON1: HDMI_A
CON2: 9_PIN_TF; 9_pin_tf
CON3: PMOD; PinHeader_2x06_P2.54mm_Vertical
J1: Z80CPU; DIP-40_W15.24mm_Socket
R1: 10k; R_Axial_DIN0207_L6.3mm_D2.5mm_P7.62mm_Horizontal
U1, U2, U5: 74LS245; DIP-20_W7.62mm_LongPads
U3, U4: SN74LVC245AN; DIP-20_W7.62mm_LongPads
U6: QMTECH_XC7A15T_35T

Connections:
A0: J1.30 (A0), U5.18 (B0)
A0_33: U5.2 (A0), U6.69 (19_V3)
A1: J1.31 (A1), U5.17 (B1)
A1_33: U5.3 (A1), U6.67 (17_V4)
A2: J1.32 (A2), U5.16 (B2)
A2_33: U5.4 (A2), U6.65 (15_U6)
A3: J1.33 (A3), U5.15 (B3)
A3_33: U5.5 (A3), U6.63 (13_R5)
A4: J1.34 (A4), U5.14 (B4)
A4_33: U5.6 (A4), U6.61 (11_R6)
A5: J1.35 (A5), U5.13 (B5)
A5_33: U5.7 (A5), U6.59 (9_T7)
A6: J1.36 (A6), U5.12 (B6)
A6_33: U5.8 (A6), U6.57 (7_U7)
A7: J1.37 (A7), U5.11 (B7)
A7_33: U5.9 (A7), U6.55 (5_V8)
A8: J1.38 (A8), U1.18 (B0)
A8_33: U1.2 (A0), U6.70 (V2_20)
A9: J1.39 (A9), U1.17 (B1)
A9_33: U1.3 (A1), U6.68 (U4_18)
A10: J1.40 (A10), U1.16 (B2)
A10_33: U1.4 (A2), U6.66 (U5_16)
A11: J1.1 (A11), U1.15 (B3)
A11_33: U1.5 (A3), U6.64 (T4_14)
A12: J1.2 (A12), U1.14 (B4)
A12_33: U1.6 (A4), U6.62 (T5_12)
A13: J1.3 (A13), U1.13 (B5)
A13_33: U1.7 (A5), U6.60 (R7_10)
A14: J1.4 (A14), U1.12 (B6)
A14_33: U1.8 (A6), U6.58 (V6_8)
A15: J1.5 (A15), U1.11 (B7)
A15_33: U1.9 (A7), U6.56 (V7_6)
BUSRQ: J1.25 (~BUSRQ)
CLOCK: J1.6 (~CLK), U4.2 (A0)
CLOCK_33: U4.18 (B0), U6.88 (N2_38)
D0: J1.14 (D0), U3.2 (A0)
D0_33: U3.18 (B0), U6.20 (D15_20)
D1: J1.15 (D1), U3.3 (A1)
D1_33: U3.17 (B1), U6.18 (E15_18)
D2: J1.12 (D2), U3.4 (A2)
D2_33: U3.16 (B2), U6.16 (G16_16)
D3: J1.8 (D3), U3.5 (A3)
D3_33: U3.15 (B3), U6.14 (H16_14)
D4: J1.7 (D4), U3.6 (A4)
D4_33: U3.14 (B4), U6.10 (E17_10)
D5: J1.9 (D5), U3.7 (A5)
D5_33: U3.13 (B5), U6.9 (9_D18)
D6: J1.10 (D6), U3.8 (A6)
D6_33: U3.12 (B6), U6.8 (F17_8)
D7: J1.13 (D7), U3.9 (A7)
D7_33: U3.11 (B7), U6.6 (G17_6)
DATADIR_33: R1.2, U3.1 (A->B), U6.32 (D13_32)
DV_CLKN: CON1.12 (CK-), U6.12 (C18_12)
DV_CLKP: CON1.10 (CK+), U6.11 (11_C17)
DV_D0N: CON1.9 (D0-), U6.15 (15_F15)
DV_D0P: CON1.7 (D0+), U6.13 (13_G15)
DV_D1N: CON1.6 (D1-), U6.19 (19_D16)
DV_D1P: CON1.4 (D1+), U6.17 (17_E16)
DV_D2N: CON1.3 (D2-), U6.22 (B17_22)
DV_D2P: CON1.1 (D2+), U6.23 (23_C16)
GND: C1.2, C2.2, C3.2, C4.2, C5.2, C6.2, C7.2, CON1.2 (D2S), CON1.5 (D1S), CON1.8 (D0S), CON1.11 (CKS), CON1.17 (GND), CON1.SH, CON2.2 (GND), CON3.3 (GND), CON3.4 (GND), J1.29 (GND), U1.10 (GND), U1.19 (CE), U2.4 (A2), U2.5 (A3), U2.10 (GND), U2.19 (CE), U3.10 (GND), U3.19 (CE), U4.6 (A4), U4.7 (A5), U4.8 (A6), U4.9 (A7), U4.10 (GND), U4.19 (CE), U5.10 (GND), U5.19 (CE), U6.3 (3_GND), U6.4 (GND_4), U6.49 (49_GND), U6.50 (GND_50), U6.53 (3_GND), U6.54 (GND_4), U6.99 (49_GND), U6.100 (GND_50)
INT: J1.16 (~INT), U4.5 (A3)
INT_33: U4.15 (B3), U6.91 (41_J5)
IORQ: J1.20 (~IORQ), U2.17 (B1)
IORQ_33: U2.3 (A1), U6.97 (47_K2)
M1: J1.27 (~M1), U2.12 (B6)
M1_33: U2.8 (A6), U6.93 (43_J6)
MERQ: J1.19 (~MREQ), U2.18 (B0)
MERQ_33: U2.2 (A0), U6.98 (K1_48)
NMI: J1.17 (~NMI)
PM_D0: CON3.5, U6.41 (41_D11)
PM_D1: CON3.6, U6.42 (D10_42)
PM_D2: CON3.7, U6.43 (43_C9)
PM_D3: CON3.8, U6.44 (D9_44)
PM_D4: CON3.9, U6.45 (45_A10)
PM_D5: CON3.10, U6.46 (B10_46)
PM_D6: CON3.11, U6.47 (47_A9)
PM_D7: CON3.12, U6.48 (B9_48)
RD: J1.21 (~RD), U2.14 (B4)
RD_33: U2.6 (A4), U6.96 (L3_46)
RESET: J1.26 (~RESET), U4.3 (A1)
RESET_33: U4.17 (B1), U6.90 (M1_40)
RFSH: J1.28 (~RFSH), U2.11 (B7)
RFSH_33: U2.9 (A7), U6.95 (45_L2)
SD_CLK: CON2.3 (CLK), U6.31 (31_C13)
SD_CMD: CON2.5 (CMD), U6.29 (29_C14)
SD_D0: CON2.4 (D0), U6.27 (27_A14)
SD_D1: CON2.7 (D1), U6.25 (25_A15)
SD_D2: CON2.8 (D2), U6.35 (35_F14)
SD_D3: CON2.6 (D3), U6.33 (33_A13)
VCC_3V3: C3.1, C4.1, CON2.1 (3V3), CON3.1 (3V3), CON3.2 (3V3), R1.1, U3.20 (VCC), U4.1 (A->B), U4.20 (VCC), U6.2 (3V3_2), U6.52 (3V3_2)
VCC_5V: C1.1, C2.1, C5.1, C6.1, C7.1, J1.11 (VCC), J1.18 (~HALT), J1.23 (~BUSACK), U1.1 (A->B), U1.20 (VCC), U2.1 (A->B), U2.20 (VCC), U5.1 (A->B), U5.20 (VCC), U6.1 (1_5V), U6.51 (1_5V)
WAIT: J1.24 (~WAIT), U4.4 (A2)
WAIT_33: U4.16 (B2), U6.89 (39_M2)
WR: J1.22 (~WR), U2.13 (B5)
WR_33: U2.7 (A5), U6.92 (J4_42)

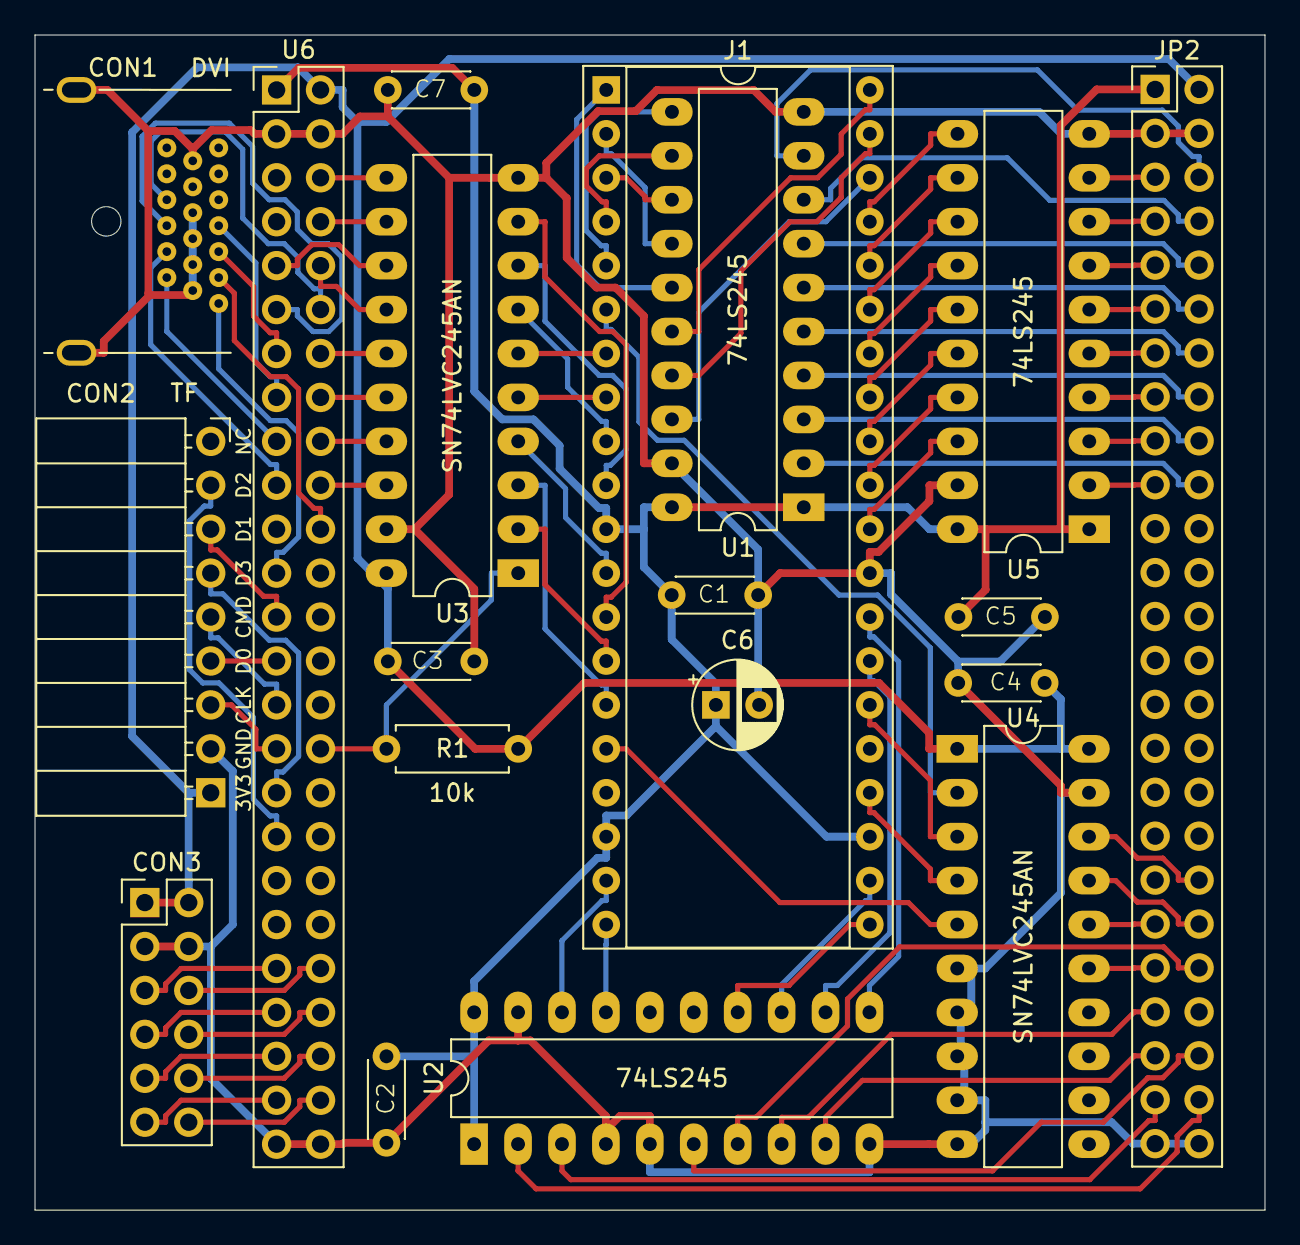
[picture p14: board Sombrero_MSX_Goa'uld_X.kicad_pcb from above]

Board: 2 copper layers, 71.1 x 67.9 mm, 18 parts (0 on the bottom side), 94 nets.

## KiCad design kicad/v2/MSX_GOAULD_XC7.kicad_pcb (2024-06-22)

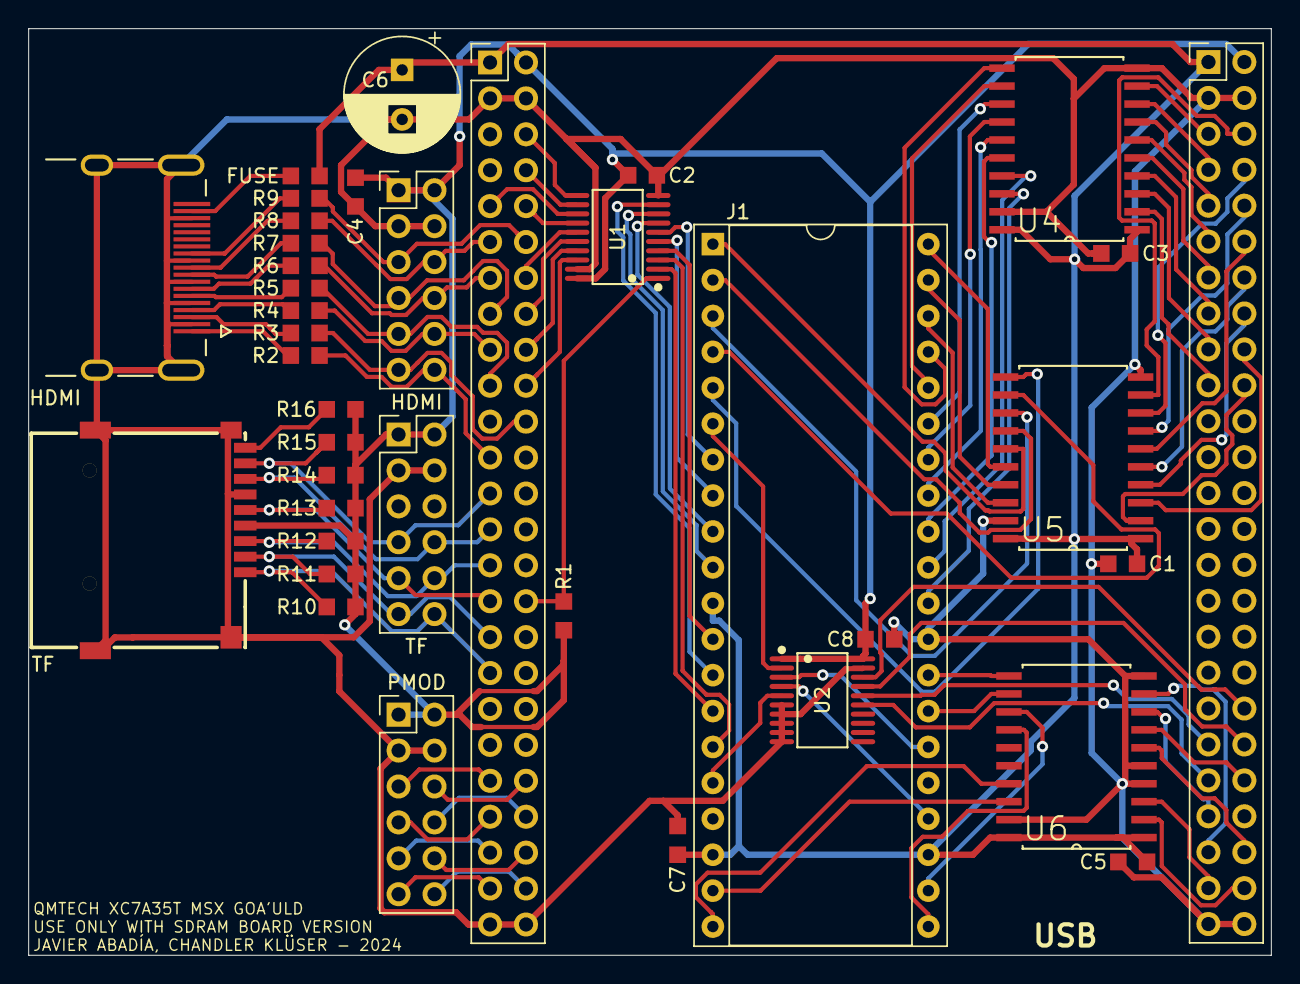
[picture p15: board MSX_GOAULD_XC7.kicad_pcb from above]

Board: 2 copper layers, 87.9 x 65.5 mm, 37 parts (0 on the bottom side), 104 nets.

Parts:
C1, C2, C3, C4, C5, C7: 100n; SMD_RES_1
C6: 100u; CP_Radial_D8.0mm_P3.50mm
C8: 0.1uF; SMD_RES_1
FUSE: FUSE; SMD_RES_1
HDMI: 2086581051; HDMI
HDMI#2: PMOD_DVI; PMOD
J1: Z80CPU; DIP-40_W15.24mm_Socket
PMOD: PMOD
R1: 10k; SMD_RES_1
R2, R3, R4, R5, R6, R7, R8, R9: 270R; SMD_RES_1
R10, R11, R12, R13, R14, R15, R16: 4.7k; SMD_RES_1
TF: TF-CARD H1.8 SY; TF-SMD_TF-012
TF#2: PMOD_TF; PMOD
U1, U2: SN74LVC245AN; TSSOP-20
U3: QMTECH_XC7A15T_35T
U4, U5, U6: 74LS245; SOIC127P1032X265-20N

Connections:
A0: J1.30 (A0), U4.18 (B0)
A0_33: U3.69 (19_V3), U4.2 (A0)
A1: J1.31 (A1), U4.17 (B1)
A1_33: U3.67 (17_V4), U4.3 (A1)
A2: J1.32 (A2), U4.16 (B2)
A2_33: U3.65 (15_U6), U4.4 (A2)
A3: J1.33 (A3), U4.15 (B3)
A3_33: U3.63 (13_R5), U4.5 (A3)
A4: J1.34 (A4), U4.14 (B4)
A4_33: U3.61 (11_R6), U4.6 (A4)
A5: J1.35 (A5), U4.13 (B5)
A5_33: U3.59 (9_T7), U4.7 (A5)
A6: J1.36 (A6), U4.12 (B6)
A6_33: U3.57 (7_U7), U4.8 (A6)
A7: J1.37 (A7), U4.11 (B7)
A7_33: U3.55 (5_V8), U4.9 (A7)
A8: J1.38 (A8), U5.18 (B0)
A8_33: U3.70 (V2_20), U5.2 (A0)
A9: J1.39 (A9), U5.17 (B1)
A9_33: U3.68 (U4_18), U5.3 (A1)
A10: J1.40 (A10), U5.16 (B2)
A10_33: U3.66 (U5_16), U5.4 (A2)
A11: J1.1 (A11), U5.15 (B3)
A11_33: U3.64 (T4_14), U5.5 (A3)
A12: J1.2 (A12), U5.14 (B4)
A12_33: U3.62 (T5_12), U5.6 (A4)
A13: J1.3 (A13), U5.13 (B5)
A13_33: U3.60 (R7_10), U5.7 (A5)
A14: J1.4 (A14), U5.12 (B6)
A14_33: U3.58 (V6_8), U5.8 (A6)
A15: J1.5 (A15), U5.11 (B7)
A15_33: U3.56 (V7_6), U5.9 (A7)
CLOCK: J1.6 (~CLK), U2.2 (A0)
CLOCK_33: U2.18 (B0), U3.88 (N2_38)
D0: J1.14 (D0), U1.2 (A0)
D0_33: U1.18 (B0), U3.20 (D15_20)
D1: J1.15 (D1), U1.3 (A1)
D1_33: U1.17 (B1), U3.18 (E15_18)
D2: J1.12 (D2), U1.4 (A2)
D2_33: U1.16 (B2), U3.16 (G16_16)
D3: J1.8 (D3), U1.5 (A3)
D3_33: U1.15 (B3), U3.14 (H16_14)
D4: J1.7 (D4), U1.6 (A4)
D4_33: U1.14 (B4), U3.10 (E17_10)
D5: J1.9 (D5), U1.7 (A5)
D5_33: U1.13 (B5), U3.9 (9_D18)
D6: J1.10 (D6), U1.8 (A6)
D6_33: U1.12 (B6), U3.8 (F17_8)
D7: J1.13 (D7), U1.9 (A7)
D7_33: U1.11 (B7), U3.6 (G17_6)
DATADIR_33: R1.2, U1.1 (A->B), U3.32 (D13_32)
DV_CLKN: HDMI#2.5 (CKN), R9.1, U3.12 (C18_12)
DV_CLKP: HDMI#2.6 (CKP), R8.1, U3.11 (11_C17)
DV_D0N: HDMI#2.7 (D0N), R7.1, U3.15 (15_F15)
DV_D0P: HDMI#2.8 (D0P), R6.1, U3.13 (13_G15)
DV_D1N: HDMI#2.9 (D1N), R5.1, U3.19 (19_D16)
DV_D1P: HDMI#2.10 (D1P), R4.1, U3.17 (17_E16)
DV_D2N: HDMI#2.11 (D2N), R3.1, U3.22 (B17_22)
DV_D2P: HDMI#2.12 (D2P), R2.1, U3.23 (23_C16)
GND: C1.2, C2.2, C3.2, C4.2, C5.2, C6.2, C7.2, C8.1, HDMI.2, HDMI.5, HDMI.8, HDMI.11, HDMI.17, HDMI.SH1 (SHIELD1), HDMI.SH2 (SHIELD2), HDMI.SH3 (SHIELD3), HDMI.SH4 (SHIELD4), HDMI#2.3 (GND), HDMI#2.4 (GND), J1.29 (GND), PMOD.3 (GND), PMOD.4 (GND), TF.6 (VSS), TF.10 (GND), TF.11 (GND), TF.12 (GND), TF.13 (GND), TF#2.3 (GND), TF#2.4 (GND), U1.10 (GND), U1.19 (CE), U2.6 (A4), U2.7 (A5), U2.8 (A6), U2.9 (A7), U2.10 (GND), U2.19 (CE), U3.3 (3_GND), U3.4 (GND_4), U3.49 (49_GND), U3.50 (GND_50), U3.53 (3_GND), U3.54 (GND_4), U3.99 (49_GND), U3.100 (GND_50), U4.10 (GND), U4.19 (CE), U5.10 (GND), U5.19 (CE), U6.4 (A2), U6.5 (A3), U6.10 (GND), U6.19 (CE)
INT: J1.16 (~INT), U2.5 (A3)
INT_33: U2.15 (B3), U3.91 (41_J5)
IORQ: J1.20 (~IORQ), U6.17 (B1)
IORQ_33: U3.97 (47_K2), U6.3 (A1)
M1: J1.27 (~M1), U6.12 (B6)
M1_33: U3.93 (43_J6), U6.8 (A6)
MERQ: J1.19 (~MREQ), U6.18 (B0)
MERQ_33: U3.98 (K1_48), U6.2 (A0)
unnamed: FUSE.2, HDMI.18
unnamed: HDMI.1, R2.2
unnamed: HDMI.3, R3.2
unnamed: HDMI.4, R4.2
unnamed: HDMI.6, R5.2
unnamed: HDMI.7, R6.2
unnamed: HDMI.9, R7.2
unnamed: HDMI.10, R8.2
unnamed: HDMI.12, R9.2
unnamed: R16.2, TF.9 (CD)
PM_D0: PMOD.5, U3.41 (41_D11)
PM_D1: PMOD.6, U3.42 (D10_42)
PM_D2: PMOD.7, U3.43 (43_C9)
PM_D3: PMOD.8, U3.44 (D9_44)
PM_D4: PMOD.9, U3.45 (45_A10)
PM_D5: PMOD.10, U3.46 (B10_46)
PM_D6: PMOD.11, U3.47 (47_A9)
PM_D7: PMOD.12, U3.48 (B9_48)
RD: J1.21 (~RD), U6.14 (B4)
RD_33: U3.96 (L3_46), U6.6 (A4)
RESET: J1.26 (~RESET), U2.3 (A1)
RESET_33: U2.17 (B1), U3.90 (M1_40)
RFSH: J1.28 (~RFSH), U6.11 (B7)
RFSH_33: U3.95 (45_L2), U6.9 (A7)
SD_CLK: R13.1, TF.5 (CLK), TF#2.9 (CLK), U3.31 (31_C13)
SD_CMD: R12.1, TF.3 (CMD), TF#2.10 (CMD), U3.29 (29_C14)
SD_D0: R14.1, TF.7 (DAT0), TF#2.8 (D0), U3.27 (27_A14)
SD_D1: R15.1, TF.8 (DAT1), TF#2.7 (D1), U3.25 (25_A15)
SD_D2: R10.1, TF.1 (DAT2), TF#2.12 (D2), U3.35 (35_F14)
SD_D3: R11.1, TF.2 (CD/DAT3), TF#2.11 (D3), U3.33 (33_A13)
VCC_3V3: C2.1, C4.1, C8.2, HDMI#2.1 (3V3), HDMI#2.2 (3V3), PMOD.1 (3V3), PMOD.2 (3V3), R1.1, R10.2, R11.2, R12.2, R13.2, R14.2, R15.2, R16.1, TF.4 (VDD), TF#2.1 (3V3), TF#2.2 (3V3), U1.20 (VCC), U2.1 (A->B), U2.20 (VCC), U3.2 (3V3_2), U3.52 (3V3_2)
VCC_5V: C1.1, C3.1, C5.1, C6.1, C7.1, FUSE.1, J1.11 (VCC), J1.18 (~HALT), J1.23 (~BUSACK), U3.1 (1_5V), U3.51 (1_5V), U4.1 (A->B), U4.20 (VCC), U5.1 (A->B), U5.20 (VCC), U6.1 (A->B), U6.20 (VCC)
WAIT: J1.24 (~WAIT), U2.4 (A2)
WAIT_33: U2.16 (B2), U3.89 (39_M2)
WR: J1.22 (~WR), U6.13 (B5)
WR_33: U3.92 (J4_42), U6.7 (A5)

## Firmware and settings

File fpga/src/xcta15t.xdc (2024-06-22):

## This file is a general .xdc for the QMTECH XC7A15T_35T_50T_CSG325
## To use it in a project:
## - uncomment the lines corresponding to used pins
## - rename the used ports (in each line, after get_ports) according to the top level signal names in the project

## Clock Signal
set_property -dict {PACKAGE_PIN R2 IOSTANDARD LVCMOS33} [get_ports ex_clk_50m]
create_clock -period 20.000 -name sys_clk_pin -waveform {0.000 10.000} -add [get_ports ex_clk_50m]

## LEDs
set_property -dict {PACKAGE_PIN D8 IOSTANDARD LVCMOS33} [get_ports {led[0]}]
set_property -dict {PACKAGE_PIN C8 IOSTANDARD LVCMOS33} [get_ports {led[1]}]

## Buttons
set_property -dict {PACKAGE_PIN H18 IOSTANDARD LVCMOS33} [get_ports s1]
set_property -dict {PACKAGE_PIN H17 IOSTANDARD LVCMOS33} [get_ports s2]

## Header JP3
#set_property -dict { PACKAGE_PIN F18   IOSTANDARD LVCMOS33 } [get_ports { jp3[5] }]; #IO_L19N_T3_A21_VREF_15 Sch=IO_F18
#set_property -dict { PACKAGE_PIN E18   IOSTANDARD LVCMOS33 } [get_ports { jp3[7] }]; #IO_L24N_T3_RS0_15 Sch=IO_E18
set_property -dict {PACKAGE_PIN D18 IOSTANDARD LVCMOS33} [get_ports {ex_bus_data[5]}]
set_property -dict {PACKAGE_PIN C17 IOSTANDARD TMDS_33} [get_ports clk_p]
set_property -dict {PACKAGE_PIN G15 IOSTANDARD TMDS_33} [get_ports {data_p[0]}]
set_property -dict {PACKAGE_PIN F15 IOSTANDARD TMDS_33} [get_ports {data_n[0]}]
set_property -dict {PACKAGE_PIN E16 IOSTANDARD TMDS_33} [get_ports {data_p[1]}]
set_property -dict {PACKAGE_PIN D16 IOSTANDARD TMDS_33} [get_ports {data_n[1]}]
#set_property -dict { PACKAGE_PIN A17   IOSTANDARD LVCMOS33 } [get_ports { jp3[21] }]; #IO_L15N_T2_DQS_ADV_B_15 Sch=IO_A17
set_property -dict {PACKAGE_PIN C16 IOSTANDARD TMDS_33} [get_ports {data_p[2]}]
set_property -dict {PACKAGE_PIN A15 IOSTANDARD LVCMOS33} [get_ports sd_dat1]
set_property -dict {PACKAGE_PIN A14 IOSTANDARD LVCMOS33} [get_ports sd_dat0]
set_property -dict {PACKAGE_PIN C14 IOSTANDARD LVCMOS33} [get_ports sd_cmd]
set_property -dict {PACKAGE_PIN C13 IOSTANDARD LVCMOS33} [get_ports sd_sclk]
set_property -dict {PACKAGE_PIN A13 IOSTANDARD LVCMOS33} [get_ports sd_dat3]
set_property -dict {PACKAGE_PIN F14 IOSTANDARD LVCMOS33} [get_ports sd_dat2]
#set_property -dict { PACKAGE_PIN B12   IOSTANDARD LVCMOS33 } [get_ports { jp3[37] }]; #IO_L7P_T1_AD2P_15 Sch=IO_B12
#set_property -dict { PACKAGE_PIN C11   IOSTANDARD LVCMOS33 } [get_ports { jp3[39] }]; #IO_L4P_T0_15 Sch=IO_C11
#set_property -dict { PACKAGE_PIN D11   IOSTANDARD LVCMOS33 } [get_ports { display_select }]; #IO_L6P_T0_15 Sch=IO_D11
#set_property -dict { PACKAGE_PIN C9    IOSTANDARD LVCMOS33 } [get_ports { a }]; #IO_L2N_T0_AD8N_15 Sch=IO_C9
#set_property -dict { PACKAGE_PIN A10   IOSTANDARD LVCMOS33 } [get_ports { d }]; #IO_L5N_T0_AD9N_15 Sch=IO_A10
#set_property -dict { PACKAGE_PIN A9    IOSTANDARD LVCMOS33 } [get_ports { g }]; #IO_L3N_T0_DQS_AD1N_15 Sch=IO_A9
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

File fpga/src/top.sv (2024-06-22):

`define ENABLE_SOUND
`define ENABLE_MAPPER
`define ENABLE_SDCARD
`define ENABLE_SCAN_LINES

module top
#(
    parameter SD_SLOT = 3
)(
    input ex_clk_50m,
    input s1,
    input s2,

    input ex_bus_wait_n,
    input ex_bus_int_n,
    input ex_bus_reset_n,
    input ex_bus_clk_3m6,

    inout [7:0] ex_bus_data,
    
    output ex_bus_m1_n,
    output ex_bus_rfsh_n,
    output reg ex_bus_mreq_n,
    output reg ex_bus_iorq_n,
    output reg ex_bus_rd_n,
    output reg ex_bus_wr_n,

    output ex_bus_data_reverse_n,
    output [15:0] ex_bus_addr,
    
    //hdmi out
    output [2:0] data_p,
    output [2:0] data_n,
    output clk_p,
    output clk_n,

    // flash
    output mspi_cs,
    //output mspi_sclk,
    inout mspi_miso,
    inout mspi_mosi,
 
    // MicroSD
    output sd_sclk,
    inout sd_cmd,      // MOSI
    inout  sd_dat0,     // MISO
    output sd_dat1,     // 1
    output sd_dat2,     // 1
    output sd_dat3,     // 1
   
    // SDRAM
    output O_sdram_clk,
    output O_sdram_cke,
    output O_sdram_cs_n,            // chip select
    output O_sdram_cas_n,           // columns address select
    output O_sdram_ras_n,           // row address select
    output O_sdram_wen_n,           // write enable
    inout [15:0] IO_sdram_dq,       // 32 bit bidirectional data bus
    output [12:0] O_sdram_addr,     // 11 bit multiplexed address bus
    output [1:0] O_sdram_ba,        // two banks
    output [1:0] O_sdram_dqm,      // 32/4
    
    output led[1:0]

    //7 segments
//    output display_select,
//    output a,
//    output b,
//    output c,
//    output d,
//    output e,
//    output f,
//    output g    

);

initial begin

end

    //clocks
    wire clk_27m;
    wire clk_81m;
    wire clk_81m_n;
    wire clk_135m;

    clk_wiz_0 pll(
        .clk_out1(clk_27m),        // MHZ main clock
        .clk_out2(clk_81m),     // MHZ phase shifted (90 degrees)
        .clk_out3(clk_81m_n),     // MHZ phase shifted (90 degrees)
        .clk_out4(clk_135m),     // hdmi pixel clock
        .clk_in1(ex_clk_50m)      // 27Mhz system clock
    ); 

    wire clk_enable_27m;
    wire clk_enable_54m;
    reg [1:0] cnt_clk_enable_27m;
    always @ (posedge clk_81m) begin
        cnt_clk_enable_27m <= cnt_clk_enable_27m + 1;
    end
    assign clk_enable_27m = ( cnt_clk_enable_27m == 2'b00 ) ? 1: 0;
    assign clk_enable_54m = ( cnt_clk_enable_27m[0] == 1 ) ? 1: 0;

    //sync input signals
    reg bus_clk_3m6;
    reg bus_wait_n;
    reg bus_int_n;
    reg [7:0] bus_data;

    always @ (posedge clk_81m) begin
        bus_clk_3m6 <= ex_bus_clk_3m6;
        bus_wait_n <= ex_bus_wait_n;
        bus_int_n <= ex_bus_int_n;
        bus_data <= ex_bus_data;
    end

    wire clk_enable_3m6;
    wire clk_falling_3m6;
    reg bus_clk_3m6_prev;
    always @ (posedge clk_81m) begin
        bus_clk_3m6_prev <= bus_clk_3m6;
    end
    assign clk_enable_3m6 = (bus_clk_3m6_prev == 0 && bus_clk_3m6 == 1);
    assign clk_falling_3m6 = (bus_clk_3m6_prev == 1 && bus_clk_3m6 == 0);


    wire bus_reset_n;
    PINFILTER dn3(
        .clk(clk_81m),
        .reset_n(1),
        .din(ex_bus_reset_n),
        .dout(bus_reset_n)
    );


    //startup logic
    reg reset1_n_ff;
    reg reset2_n_ff;
    reg reset3_n_ff;
    wire reset1_n;
    wire reset2_n;
    wire reset3_n;

    reg [15:0] counter_reset = 0;
    reg [1:0] rst_seq;
    reg rst_step;

    always @ (posedge clk_27m or negedge bus_reset_n) begin
        if (bus_reset_n == 0) begin
            rst_step <= 0;
            counter_reset <= 0;
        end
        else begin
            rst_step <= 0;
            if ( counter_reset <= 16'h8000 ) 
                counter_reset <= counter_reset + 1;
            else begin
                rst_step <= 1;
                counter_reset <= 0;
            end
        end
    end

    always @ (posedge clk_27m or negedge bus_reset_n or posedge ram_fail_w) begin
        if (bus_reset_n == 0 || ram_fail_w == 1) begin
            rst_seq <= 2'b00;
            reset1_n_ff <= 0;
            reset2_n_ff <= 0;
            reset3_n_ff <= 0;
        end
        else begin
            case ( rst_seq )
                2'b00: 
                    if (rst_step == 1 ) begin
                        reset1_n_ff <= 1;
                        rst_seq <= 2'b01;
                    end
                2'b01: 
                    if (rst_step == 1) begin
                        reset2_n_ff <= 1;
                        rst_seq <= 2'b10;
                    end
                2'b10:
                    if (rst_step == 1) begin
                        reset3_n_ff <= 1;
                        rst_seq <= 2'b11;
                    end
            endcase
        end
    end
    assign reset1_n = reset1_n_ff;
    assign reset2_n = reset2_n_ff;
    assign reset3_n = reset3_n_ff;


    //bus isolation
    wire bus_data_reverse;
    wire bus_m1_n;
    wire bus_mreq_n;
    wire bus_iorq_n;
    wire bus_rd_n;
    wire bus_wr_n;
    wire bus_rfsh_n;
    reg [7:0] cpu_din;
    wire [7:0] cpu_dout;
    wire bus_mreq_disable;
    wire bus_iorq_disable;
    wire bus_disable;
    assign ex_bus_m1_n = bus_m1_n;
    assign ex_bus_rfsh_n = bus_rfsh_n;
    assign ex_bus_data_reverse_n = ~ bus_data_reverse;
    //assign ex_bus_mreq_n = bus_mreq_n;
    //assign ex_bus_iorq_n = bus_iorq_n;
    //assign ex_bus_rd_n = bus_rd_n;
    //assign ex_bus_wr_n = bus_wr_n;
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

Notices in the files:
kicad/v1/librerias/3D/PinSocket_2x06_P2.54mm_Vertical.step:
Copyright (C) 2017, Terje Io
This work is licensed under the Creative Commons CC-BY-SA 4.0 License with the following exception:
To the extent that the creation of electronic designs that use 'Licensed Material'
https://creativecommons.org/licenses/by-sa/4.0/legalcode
